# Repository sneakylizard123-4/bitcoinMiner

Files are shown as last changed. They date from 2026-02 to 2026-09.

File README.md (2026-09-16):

# BitcoinMiner

A single BM1370 board that mines bitcoin

## Custom Features
- BM1370 ASIC miner
- ESP32-S3-WROOM-1/1u-N16R8 MCU for wifi
- 9x WS2812B status LEDs
- Fan controller
- TPS546D24 20A core regulator
- USB-C + TC2030 Tag-Connect

## PCB Design

The board is a 4 layer 100x75mm PCB with a dedicated ground inner layer

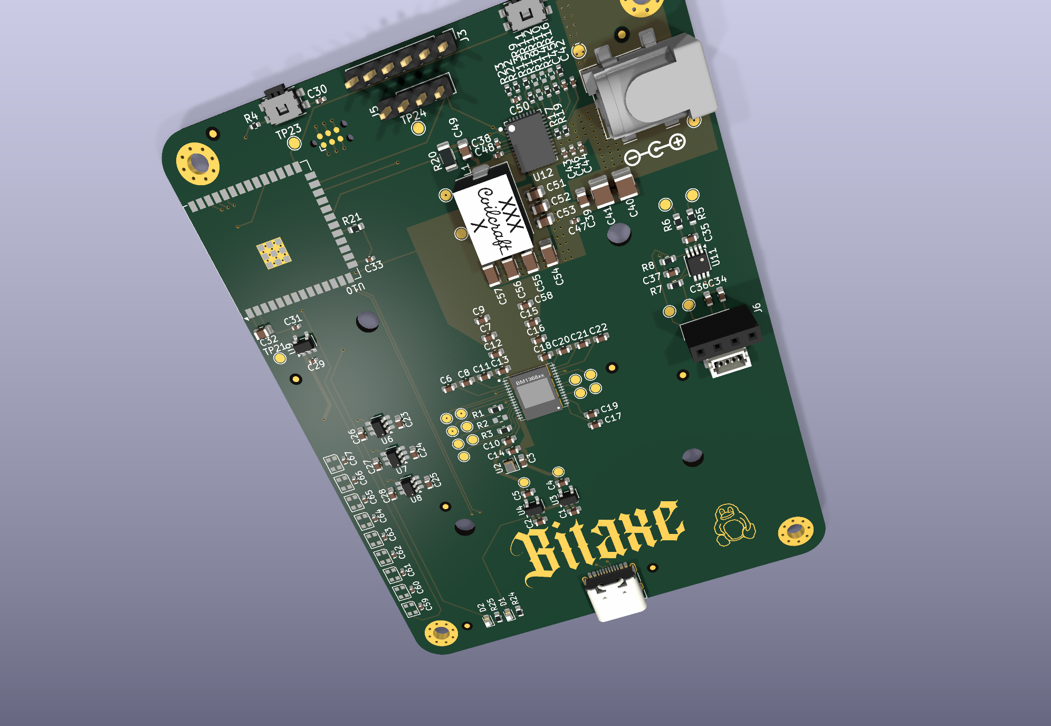
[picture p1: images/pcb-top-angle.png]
PCB 3D / layout image


It is built around the BM1370 ASIC.
it is based on the proven Bitaxe Gamma reference design, and a buck 20A 1.2V core rail.
The ESP32-S3 module provides WiFi/BLE control. It can be programmed through the native USB-C port or the Tag-Connect debug header
The fan controller communicates to the ESP32 via i2C

## Firmware

The firmware is the open-source
see [firmware/](firmware/). 
To enter program mode:
1. Hold BOOT (SW2)
2. Press RESET (SW1)
3. Release BOOT
4. Start flashing

```
pip install bitaxetool
bitaxetool --config firmware/configs/config-bitcoinMiner.csv --firmware firmware/esp-miner-merged.bin
```

## BOM (Bill of Materials)

| Ref | Value | LCSC # | MPN | Manufacturer | Footprint | Qty | Unit $ | Ext $ | Link |
|-----|---|---|-----|---|---|-----|---|---|---|
| C1,C2,C4-C22,C58 | 1uF 16V X7R | C59782 | CL10B105KO8NNNC | Samsung | 0603 | 22 | — | — | [LCSC](https://www.lcsc.com/product-detail/C59782.html) |
| C3,C23-C28,C36,C37 | 0.1uF 16V X7R | C66501 | CL10B104KO8NNNC | Samsung | 0603 | 9 | — | — | [LCSC](https://www.lcsc.com/product-detail/C66501.html) |
| C29,C30,C31,C38,C42,C44 | 1uF 16V X5R | C2177690 | EMK105BJ105MV | Taiyo Yuden | 0402 | 6 | — | — | [LCSC](https://www.lcsc.com/product-detail/C2177690.html) |
| C32,C39 | 10uF 16V X5R | C1713 | CL21A106KOQNNNE | Samsung | 0805 | 2 | — | — | [LCSC](https://www.lcsc.com/product-detail/C1713.html) |
| C33,C45,C48,C59-C67 | 0.1uF 16V X5R | C159816 | CL05A104KO5NNNC | Samsung | 0402 | 12 | — | — | [LCSC](https://www.lcsc.com/product-detail/C159816.html) |
| C34 | 47uF 6.3V X5R | C140782 | GRM188R60J476ME15D | muRata | 0603 | 1 | — | — | [LCSC](https://www.lcsc.com/product-detail/C140782.html) |
| C35 | 470pF 50V C0G | C36252 | 0603CG471J500NT | FH | 0603 | 1 | — | — | [LCSC](https://www.lcsc.com/product-detail/C36252.html) |
| C40,C41 | 47uF 16V X5R | C2932477 | CL32A476KOJNNNE | Samsung | 1210 | 2 | — | — | [LCSC](https://www.lcsc.com/product-detail/C2932477.html) |
| C43 | 4700pF 50V X7R | C599603 | C0402C472K5RAC7867 | KEMET | 0402 | 1 | — | — | [LCSC](https://www.lcsc.com/product-detail/C599603.html) |
| C46 | 2200pF 50V X7R | C106861 | CC0402KRX7R9BB222 | YAGEO | 0402 | 1 | — | — | [LCSC](https://www.lcsc.com/product-detail/C106861.html) |
| C47 | 4.7uF 6.3V X5R | C82453 | GRM155R60J475ME47D | muRata | 0402 | 1 | — | — | [LCSC](https://www.lcsc.com/product-detail/C82453.html) |
| C49 | 1000pF 50V NP0 | C152850 | 0805N102J500CT | Walsin | 0805 | 1 | — | — | [LCSC](https://www.lcsc.com/product-detail/C152850.html) |
| C50 | 100pF 50V C0G | C597014 | 04025A101JAT2A | AVX | 0402 | 1 | — | — | [LCSC](https://www.lcsc.com/product-detail/C597014.html) |
| C51,C52,C53 | 22uF 10V X5R | C441864 | GRM21BR61A226ME44L | muRata | 0805 | 3 | — | — | [LCSC](https://www.lcsc.com/product-detail/C441864.html) |
| C54-C57 | 100uF 6.3V X5R | C15008 | CL31A107MQHNNNE | Samsung | 1206 | 4 | — | — | [LCSC](https://www.lcsc.com/product-detail/C15008.html) |
| D1,D2 | Green LED 0603 | C12624 | KT-0603G | Hubei KENTO | 0603 | 2 | — | — | [LCSC](https://www.lcsc.com/product-detail/C12624.html) |
| D3-D11 | WS2812B-2020 | C965555 | WS2812B-2020 | Worldsemi | PLCC4 2020 | 9 | — | — | [LCSC](https://www.lcsc.com/product-detail/C965555.html) |
| J1 | DC Barrel Jack 2.0x5.5mm | C431534 | 694106106102 | Wuerth | Through Hole | 1 | — | — | [LCSC](https://www.lcsc.com/product-detail/C431534.html) |
| J4 | USB-C Receptacle 16P | C165948 | TYPE-C-31-M-12 | Korean Hroparts Elec | SMD | 1 | — | — | [LCSC](https://www.lcsc.com/product-detail/C165948.html) |
| J6 | Pin Socket 1x4 2.54mm | C2718488 | 2.54-1\*4P | BOOMELE | Through Hole | 1 | — | — | [LCSC](https://www.lcsc.com/product-detail/C2718488.html) |
| J7 | JST SH 4P 1mm | C160390 | BM04B-SRSS-TB(LF)(SN) | JST | SMD | 1 | — | — | [LCSC](https://www.lcsc.com/product-detail/C160390.html) |
| L1 | 300nH Shielded Inductor | — | SLC1175-271MEC | Coilcraft | SMD 11x17mm | 1 | — | — | — |
| R1,R3 | 1K 1% | C22548 | RC0603FR-071KL | YAGEO | 0603 | 2 | — | — | [LCSC](https://www.lcsc.com/product-detail/C22548.html) |
| R13 | 14.7k 1% | C4021671 | CRCW040214K7FKTD | Vishay | 0402 | 1 | — | — | [LCSC](https://www.lcsc.com/product-detail/C4021671.html) |
| R14 | 0 ohm | C881153 | CR0402J0R00Q10Z | Ever Ohms | 0402 | 1 | — | — | [LCSC](https://www.lcsc.com/product-detail/C881153.html) |
| R16 | 3.74k 1% | C2085340 | CRCW04023K74FKED | Vishay | 0402 | 1 | — | — | [LCSC](https://www.lcsc.com/product-detail/C2085340.html) |
| R17 | 11.8k 1% | C324858 | RC-02K1182FT | FH | 0402 | 1 | — | — | [LCSC](https://www.lcsc.com/product-detail/C324858.html) |
| R18 | 68.1k 1% | C844116 | CRCW040268K1FKED | Vishay | 0402 | 1 | — | — | [LCSC](https://www.lcsc.com/product-detail/C844116.html) |
| R19 | 10 1% | C138066 | RC0402FR-0710RL | YAGEO | 0402 | 1 | — | — | [LCSC](https://www.lcsc.com/product-detail/C138066.html) |
| R20 | 1 ohm 0.1% sense | C2912606 | HoAR1206-1/4W-1R-0.1% | Milliohm | 1206 | 1 | — | — | [LCSC](https://www.lcsc.com/product-detail/C2912606.html) |
| R8,R21,R24,R25 | 10k 1% | C98220 | RC0603FR-0710KL | YAGEO | 0603 | 4 | — | — | [LCSC](https://www.lcsc.com/product-detail/C98220.html) |
| R22,R23 | 49.9 1% | C482189 | CRCW040249R9FKED | Vishay | 0402 | 2 | — | — | [LCSC](https://www.lcsc.com/product-detail/C482189.html) |
| R4 | 10k 1% | C60490 | RC0402FR-0710KL | YAGEO | 0402 | 1 | — | — | [LCSC](https://www.lcsc.com/product-detail/C60490.html) |
| R5,R6 | 100 1% | C100700 | CR0603FA1000G | LIZ | 0603 | 2 | — | — | [LCSC](https://www.lcsc.com/product-detail/C100700.html) |
| R7 | 5.6K 1% | C844799 | CRCW06035K60FKEA | Vishay | 0603 | 1 | — | — | [LCSC](https://www.lcsc.com/product-detail/C844799.html) |
| R9 | 8.25k 1% | C185389 | RC0402FR-078K25L | YAGEO | 0402 | 1 | — | — | [LCSC](https://www.lcsc.com/product-detail/C185389.html) |
| SW1,SW2 | Tactile Switch EVQPU | — | EVQPUM02K | PANASONIC | SMD | 2 | — | — | — |
| U10 | ESP32-S3-WROOM-1N16R8 | C2913202 | ESP32-S3-WROOM-1-N16R8 | ESPRESSIF | SMD WROOM | 1 | — | — | [LCSC](https://www.lcsc.com/product-detail/C2913202.html) |
| U11 | EMC2101 | C626968 | EMC2101-R-ACZL-TR | Microchip | TSSOP-8 | 1 | — | — | [LCSC](https://www.lcsc.com/product-detail/C626968.html) |
| U12 | TPS546D24ARVFR | C507280 | TPS546D24ARVFR | TI | LQFN-40 | 1 | — | — | [LCSC](https://www.lcsc.com/product-detail/C507280.html) |
| U2 | 25MHz Crystal | C843258 | NX2016SA-25MHZ-STD-CZS-2 | NDK | 2016-4P | 1 | — | — | [LCSC](https://www.lcsc.com/product-detail/C843258.html) |
| U3 | TLV75712PDBV | C1509296 | TLV75712PDBVR | TI | SOT-23-5 | 1 | — | — | [LCSC](https://www.lcsc.com/product-detail/C1509296.html) |
| U4 | MCP1824T-0802E | C625460 | MCP1824T-0802E/OT | Microchip | SOT-23-5 | 1 | — | — | [LCSC](https://www.lcsc.com/product-detail/C625460.html) |
| U5 | BM1370 | — | BM1370 | Bitmain | LQFP | 1 | — | — | — |
| U6,U7,U8 | SN74LVC1T45DBV | C7843 | SN74LVC1T45DBVR | TI | SOT-23-6 | 3 | — | — | [LCSC](https://www.lcsc.com/product-detail/C7843.html) |
| U9 | TLV75733PDBV | C485517 | TLV75733PDBVR | TI | SOT-23-5 | 1 | — | — | [LCSC](https://www.lcsc.com/product-detail/C485517.html) |
| **Total** | — | — | — | — | — | **116** | — | — | — |

Full CSVs: [LCSC BOM](BOM.csv)
[KiCad generated BOM](kicad/production/bom.csv)
[Pick and place](kicad/production/positions.csv)

## Production

Using JLCPCB
4-Layer
- HASL Lead Free
- 1.6mm thick board

## Credits

- [Bitaxe Gamma](https://github.com/bitaxeorg/BitaxeGamma) - reference schematic and BM1370 support circuitry
- [ESP-Miner](https://github.com/bitaxeorg/ESP-Miner) - firmware this board's target is based on
- [Hack Club](https://hackclub.com/) - funding through Forge

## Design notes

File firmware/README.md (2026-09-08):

# bitcoinMiner Firmware

ESP32-S3 mining firmware for the bitcoinMiner board, based on the open-source
[bitaxe ESP-Miner](https://github.com/bitaxeorg/ESP-Miner) firmware (GPL-3.0,
ESP-IDF v6.0.x). The entire upstream tree is vendored under `firmware/` with a
custom **BitcoinMiner** board target added, so the board tunnels a single
BitMiner BM1370 ASIC at ~525 MHz / 1.15 V core like a Bitaxe Gamma.

## Board target

Added to the upstream ESP-Miner:

| File | Change |
|---|---|
| `main/device_pins.h` / `main/device_pins.c` | `BITCOINMINER_I2C_PINS` (SDA=48, SCL=47) |
| `main/device_config.h` | `BITCOINMINER` family + `board_version = "bitcoinMiner"` config |
| `configs/config-bitcoinMiner.csv` | NVS config flashed with `bitaxetool` |

Board version string: **`bitcoinMiner`**

### How the board is selected

`device_config_init()` (in `device_config.c`) looks up `boardversion` from NVS
against `default_configs[]`. The `bitcoinMiner` entry selects:

- Family `BitcoinMiner`: 1x BM1370, default 525 MHz, 1150 mV, 128 cores, 4 hash domains
- `BITCOINMINER_PINS`: I2C SDA=GPIO48, SCL=GPIO47 (EMC2101 at 0x4C, TPS546D24 at 0x24 on PMBus)
- `EMC2101` fan/temp controller enabled (ideality 0x24, beta 0x00)
- `TPS546` PMBus core regulator enabled (VOUT 1.2 V core rail)
- No BAP, no display (`.bap = NULL, .i80 = NULL`)
- `asic_enable = false`, `plug_sense = false` (core power is always on via TPS546; barrel jack has no sense pin)

## ESP32 pin map

| Signal | ESP32-S3 GPIO | Notes |
|---|---|---|
| ASIC serial TX (→U7→BM1370 CI) | GPIO17 | UART1, hardcoded in `components/asic/serial.c` |
| ASIC serial RX (←U8←BM1370 RO) | GPIO18 | UART1 |
| ASIC reset (→U6→BM1370 NRSTI) | GPIO1 | `CONFIG_GPIO_ASIC_RESET`, default already 1 |
| I2C SDA (EMC2101, TPS546D24) | GPIO48 | `BITCOINMINER_I2C_PINS` |
| I2C SCL | GPIO47 | |
| WS2812B LED chain (D3–D11) | GPIO38 | Not driven by ESP-Miner (no RGB LED support); reserved |
| Boot button (SW2) | GPIO0 | default boot button |
| USB D− / D+ | GPIO19 / GPIO20 | USB-C flashing |
| UART0 console (J2 TC2030) | GPIO43 (RX) / GPIO44 (TX) | debug |
| Board LED D2 | GPIO21 | not used by firmware |
| TPS546 Power Good (PGD) | GPIO11 | not used by firmware |
| TPS546 SMB_ALERT | GPIO13 | not used by firmware |

GPIO2 is tied to the 1.2 V ASIC core rail on the PCB — do not configure it as an output.

## Build

Requires ESP-IDF v6.0.x for ESP32-S3 and Node.js ≥ 22 (the AxeOS web UI is
compiled into the binary). See upstream `AGENTS.md` / `readme.md` for the exact
SDK and the official devcontainer if you don't want to install the toolchain.

```
cd firmware
git clone ... # upstream expects the libsecp256k1 component vendored here already
. $HOME/esp/v6.0.2/esp-idf/export.sh
idf.py set-target esp32s3
idf.py build
./merge_bin.sh ./esp-miner-merged.bin
```

## Flash

Install [bitaxetool](https://pypi.org/project/bitaxetool/):

```
pip install bitaxetool
bitaxetool --config ./configs/config-bitcoinMiner.csv --firmware ./esp-miner-merged.bin
```

Or flash over USB-C (J4) / TC2030 (J2):

1. Hold **SW1** (boot) and press **SW2** (reset) to enter download mode.
2. `esptool.py --chip esp32s3 --port /dev/ttyACM0 write_flash 0x0 esp-miner-merged.bin`
3. Press **SW2** (reset) to boot, then configure WiFi/pool from the AxeOS UI
   (captive portal AP `bitcoinminer`).

## What's not wired up

- **WS2812B status LEDs (GPIO38)**: upstream ESP-Miner has no RGB/LED-strip
  support, so the LED chain stays dark. Wiring it to the firmware would need a
  new feature (e.g. led_strip + status colors) that doesn't exist upstream.
- **Board LED D2 (GPIO21)** and TPS546 PGD/SMB_ALERT (GPIO11/13) are reserved
  but unused by the firmware.

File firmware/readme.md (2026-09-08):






Repobeats analytics image

# ESP-Miner
esp-miner is open source ESP32 firmware for the [Bitaxe](https://github.com/bitaxeorg/bitaxe)

## Community
The ESP-Miner firmware is maintained by OSMU which hosts it's own discussion forum at [Forum](https://osmu.xyz).

If you are looking for premade images to load on your Bitaxe, check out the [latest release](https://github.com/bitaxeorg/ESP-Miner/releases/latest) page. Maybe you want [instructions](https://github.com/bitaxeorg/ESP-Miner/blob/master/flashing.md) for loading factory images.

# Bitaxetool
We also have a command line python tool for flashing Bitaxe and updating the config called Bitaxetool 

**Bitaxetool Requires Python3.4 or later and pip**

Install bitaxetool from pip. pip is included with Python 3.4 but if you need to install it check <https://pip.pypa.io/en/stable/installation/>

```
pip install --upgrade bitaxetool
```
The bitaxetool includes all necessary library for flashing the binaries to the Bitaxe Hardware.

**Notes**
 - The bitaxetool does not work properly with esptool v5.x.x, esptool v4.9.0 or earlier is required.
 - Bitaxetool v0.6.1 - locked to using esptool v4.9.0

```
pip install bitaxetool==0.6.1
```

- Flash a "factory" image to a Bitaxe to reset to factory settings. Make sure to choose an image built for your hardware version (401) in this case:

```
bitaxetool --firmware ./esp-miner-factory-401-v2.4.2.bin
```
- Flash just the NVS config to a bitaxe:

```
bitaxetool --config ./configs/config-401.csv
```
- Flash both a factory image _and_ a config to your Bitaxe: note the settings in the config file will overwrite the config already baked into the factory image:

```
bitaxetool --config ./configs/config-401.csv --firmware ./esp-miner-factory-401-v2.4.2.bin
```

## AxeOS API
The esp-miner UI is called AxeOS and provides an API to expose actions and information.

For more details take a look at [`main/http_server/openapi.yaml`](./main/http_server/openapi.yaml).

Available API endpoints:
  
**GET**

* `/api/system/info` Get system information
* `/api/system/asic` Get ASIC settings information
* `/api/system/statistics` Get system statistics (data logging should be activated)
* `/api/system/statistics/dashboard` Get system statistics for dashboard
* `/api/system/scoreboard` Get top 20 highest difficulty shares
* `/api/system/wifi/scan` Scan for available Wi-Fi networks
* `/api/system/logs` Download system logs

**POST**

* `/api/system/restart` Restart the system
* `/api/system/identify` Identify the device
* `/api/system/OTA` Update system firmware
* `/api/system/OTAWWW` Update AxeOS

**PATCH**

* `/api/system` Update system settings

**WEBSOCKETS**

* `/api/ws` Text stream log
* `/api/ws/live` JSONp stream of partial system info updates

### API examples in `curl` (works with IP addresses or .local hostnames):

```bash
# Get system information
curl http://YOUR-BITAXE-IP/api/system/info

# Get ASIC settings information
curl http://YOUR-BITAXE-IP/api/system/asic

# Get system statistics
curl http://YOUR-BITAXE-IP/api/system/statistics

# Get dashboard statistics
curl http://YOUR-BITAXE-IP/api/system/statistics/dashboard

# Get available Wi-Fi networks
curl http://YOUR-BITAXE-IP/api/system/wifi/scan

# Download system logs
curl http://YOUR-BITAXE-IP/api/system/logs

# Restart the system
curl -X POST http://YOUR-BITAXE-IP/api/system/restart

# Pause mining
curl -X POST http://YOUR-BITAXE-IP/api/system/pause

# Resume mining
curl -X POST http://YOUR-BITAXE-IP/api/system/resume

# Let the device say Hi!
curl -X POST http://YOUR-BITAXE-IP/api/system/identify

# Update system firmware
curl -X POST \
     -H "Content-Type: application/octet-stream" \
     --data-binary "@esp-miner.bin" \
     http://YOUR-BITAXE-IP/api/system/OTA

# Update with a custom AxeOS Web UI partition (www.bin)
curl -X POST \
     -H "Content-Type: application/octet-stream" \
     --data-binary "@www.bin" \
     http://YOUR-BITAXE-IP/api/system/OTAWWW

# Update system settings
curl -X PATCH http://YOUR-BITAXE-IP/api/system \
     -H "Content-Type: application/json" \
     -d '{"fanspeed": "desired_speed_value"}'

# Configure a Stratum V1 Pool (Slot Index 0)
curl -X PUT http://YOUR-BITAXE-IP/api/system/pools/0 \
     -H "Content-Type: application/json" \
     -d '{
       "stratumProtocol": "SV1",
       "stratumURL": "solo.ckpool.org",
       "stratumPort": 3333,
       "stratumUser": "1A1zP1eP5QGefi2DMPTfTL5SLmv7DivfNa.worker1",
       "stratumPassword": "x",
       "stratumSuggestedDifficulty": 0,
       "stratumExtranonceSubscribe": true,
       "stratumTLS": 0,
       "stratumDecodeCoinbase": true
     }'

# Configure a Stratum V2 Pool (Slot Index 1)
curl -X PUT http://YOUR-BITAXE-IP/api/system/pools/1 \
     -H "Content-Type: application/json" \
     -d '{
       "stratumProtocol": "SV2",
       "stratumURL": "v2.srtm.ocean.xyz",
       "stratumPort": 3334,
       "stratumUser": "1A1zP1eP5QGefi2DMPTfTL5SLmv7DivfNa.worker1",
       "stratumPassword": "x",
       "stratumSuggestedDifficulty": 0,
       "stratumExtranonceSubscribe": true,
       "stratumTLS": 0,
       "stratumDecodeCoinbase": true,
       "stratumV2ChannelType": "extended",
       "stratumV2AuthorityPubkey": "your_base58_sv2_authority_public_key"
     }'

# Stream logs
websocat ws://YOUR-BITAXE-IP/api/ws

# Stream Info API
websocat ws://YOUR-BITAXE-IP/api/ws/live
```

## mDNS Support

ESP-Miner now includes comprehensive mDNS (multicast DNS) support for seamless network discovery and device accessibility. This feature enables automatic device discovery on local networks without requiring manual IP address configuration.

### Features

- **Automatic mDNS Initialization**: Device automatically registers with mDNS/Bonjour/Avahi services on network connection
- **Dynamic Hostname Registration**: Device hostname is registered as `<hostname>.local` (e.g., `bitaxe.local`)
- **Service Advertisement**: HTTP service is advertised as `_http._tcp` on port 80
- **AxeOS Subtype**: Advertises `_axeos._sub._http._tcp` for targeted DNS-SD discovery of AxeOS devices
- **Device TXT Records**: Includes board version, family, ASIC model, ASIC count, and firmware version as DNS-SD TXT records
- **Dynamic Hostname Updates**: mDNS hostname updates automatically when device hostname is changed via web interface
- **Hostname Normalization**: Automatically strips `.local` suffix when setting hostnames to prevent duplicate registrations
- **CORS Support**: Enhanced CORS handling to allow requests from mDNS hostnames
- **Hostname Conflict Resolution**: Automatically detects and resolves hostname conflicts by appending MAC address suffix when needed
- **Enhanced Swarm Discovery**: Swarm mode supports both IP addresses and .local hostnames for seamless network management

### Network Discovery

Once connected to your local network, the device becomes discoverable through:

```bash
# Using avahi-browse (Linux)
avahi-browse _http._tcp

# Discover AxeOS devices specifically
avahi-browse _axeos._sub._http._tcp

# Using dns-sd (macOS)
dns-sd -B _http._tcp

# Discover AxeOS devices with TXT records
dns-sd -B _axeos._sub._http._tcp

# Direct access
http://<hostname>.local
```

### Configuration

- **Default Hostname**: `bitaxe` (configurable via web interface)
- **Service Type**: `_http._tcp`
- **Subtype**: `_axeos._sub._http._tcp`
- **Port**: `80`
- **Instance Name**: `Bitaxe <family> <board> (<mac_suffix>)` (e.g., `Bitaxe Gamma 601 (A1B2)`)
- **TXT Records**: `board`, `family`, `asic`, `asic_count`, `fw_version`

### Hostname Conflict Resolution

If multiple devices attempt to use the same hostname, ESP-Miner automatically resolves conflicts by appending a MAC address-derived suffix (e.g., `bitaxe-12ab` if `bitaxe` is taken). This ensures unique network identification without manual intervention.

### Benefits

- **Zero-Configuration Discovery**: Devices automatically appear in network browsers
- **Cross-Platform Compatibility**: Works with Windows, macOS, Linux, and mobile devices
- **No IP Address Required**: Access devices using human-readable names
- **Automatic Resolution**: DNS resolution happens transparently in the background
- **Zero-Configuration Swarm Management**: Automatic device discovery and management without IP configuration
- **Enhanced Cross-Platform Compatibility**: Improved support across different network environments and discovery protocols

## Administration

The firmware hosts a small web server on port 80 for administrative purposes. Once the Bitaxe device is connected to the local network, the admin web front end may be accessed via a web browser connected to the same network at `http://<IP>`, replacing `IP` with the LAN IP address of the Bitaxe device, or `http://bitaxe`, provided your network supports mDNS configuration.

### Recovery

In the event that the admin web front end is inaccessible, for example because of an unsuccessful custom Web UI update, a recovery page can be accessed at `http://<IP>/recovery`.

### Unlock Settings

In order to unlock the Input fields for ASIC Frequency and ASIC Core Voltage you need to append `?oc` to the end of the settings tab URL in your browser. Be aware that without additional cooling overclocking can overheat and/or damage your Bitaxe.

## Unified Firmware & Rollbacks

Starting with the unified firmware releases, ESP-Miner uses a unified architecture where the AxeOS frontend is compiled, gzipped, and embedded directly into the firmware application binary (`esp-miner.bin`). 

A separate Web UI image (`www.bin`) is no longer required for standard usage since the web interface is served directly from the firmware. If you want to use a custom or modified AxeOS frontend, you can still enable the **custom web UI** option in the settings. This allows you to upload and serve a separate `www.bin` from the SPIFFS partition, which takes priority over the built-in assets.

### Disabling Custom Web UI via Recovery Page or API

If a device is stuck serving an older custom `www.bin` partition and the Web UI settings option is not accessible, you can disable custom WWW and revert to the embedded AxeOS interface by visiting the recovery page in your browser:

```
http://<IP>/recovery
```

Alternatively, you can disable `useCustomWWW` directly via the REST API:

```bash
# Disable custom Web UI (revert to embedded AxeOS)
curl -X PATCH http://YOUR-BITAXE-IP/api/system \
     -H "Content-Type: application/json" \
     -d '{"useCustomWWW": 0}'

# Restart the device to apply changes
curl -X POST http://YOUR-BITAXE-IP/api/system/restart
```

### Rollback to Pre-Unified Firmware

If you roll back the firmware from a unified version to an older, pre-unified version (which expects a separate web partition):

- **www partition persistence**: The `www` (SPIFFS) partition on the flash chip will remain untouched during the rollback, keeping whatever latest non-unified Web UI version was last active on the device.
- **Potential UI Version Mismatch**: Since older firmware relies entirely on the separate `www` partition to serve the web interface, the device will load whatever files exist in that partition. If you experience layout errors or missing features after rolling back, you will need to manually flash or upload a compatible `www.bin` version that matches the older firmware version.

## Development using esp-miner/devcontainer

This configuration allows you to edit locally and compile the source code using a docker container so you don't have to install the ESP-IDF toolchain and other supporting software on your computer to compile the firmware.

### Prerequisites

- Docker server

### Local PC Setup

These instructions will assume an installation to your home directory.
```
cd ~
git clone --recursive https://github.com/bitaxeorg/ESP-MINER.git
cd ESP-MINER
git checkout <the branch you want>
git submodule update --init --recursive
# The next step builds the docker container that will compile the source code
# This will take several minutes to finish
docker build -t espminer-build .devcontainer
```
### Building

```
cd ~/ESP-MINER
docker run --rm -it -v $PWD:/workspace espminer-build /bin/bash
git config --global --add safe.directory /workspace    # set git permissions or build will fail; only done once
cd /workspace
idf.py build
```	
Once the build is done exit out of the docker session and flash the new firmware.

## Development

### Prerequisites

- Install the ESP-IDF toolchain from https://docs.espressif.com/projects/esp-idf/en/stable/esp32/get-started/
- Install nodejs/npm from https://nodejs.org/en/download
- (Optional) Install the ESP-IDF extension for VSCode from https://marketplace.visualstudio.com/items?itemName=espressif.esp-idf-extension

### Cloning

This project uses git submodules (e.g. libsecp256k1). Clone with `--recursive`:
```
git clone --recursive https://github.com/bitaxeorg/ESP-Miner.git
```

If you already have a checkout, initialize the submodules with:
```
git submodule update --init --recursive
```

### Building

At the root of the repository, run:
```
idf.py build && ./merge_bin.sh ./esp-miner-merged.bin
```

Note: the merge_bin.sh script is a custom script that merges the bootloader, partition table, and the application binary into a single file.

Note: if using VSCode, you may have to configure the settings.json file to match your esp hardware version. For example, if your bitaxe has something other than an esp32-s3, you will need to change the version in the `.vscode/settings.json` file.

### Flashing

With the bitaxe connected to your computer via USB, run:

```
bitaxetool --config ./configs/config-xxx.csv --firmware ./esp-miner-merged.bin
```

where xxx is the config file for your hardware version. You can see the list of available config files in the `configs` directory.

A custom board version is also possible with `configs/config-custom.csv`. A custom board needs to be based on an existing `devicemodel` and `asicmodel`.

**Notes:** 
  - If you are developing within a dev container, you will need to run the bitaxetool command from outside the container. Otherwise, you will get an error about the device not being found.
  - Some Bitaxe versions can't directly connect to a USB-C port. If yours is affected use a USB-A adapter as a workaround. More about it [here](https://github.com/bitaxeorg/bitaxeGamma/issues/37).
  - Only ESP32-S3-WROOM-1 module type N16R8 (16MB Flash, 8MB Octal SPI PSRAM) is supported. This model number should be visible on the ESP32 module. Other module types without PSRAM or with Quad SPI PSRAM will not work with the normal firmware. More about it [here](https://github.com/bitaxeorg/ESP-Miner/issues/826).

### Wi-Fi routers

There are some Wi-Fi routers that will block mining, ASUS Wi-Fi routers & some TP-Link Wi-Fi routers for example.
If you find that your not able to mine / have no hash rate you will need to check the Wi-Fi routers settings and disable the following;

1/ AiProtection

2/ IoT 

If your Wi-Fi router has both of these options you might have to disable them both.

If your still having problems here, check other settings within the Wi-Fi router and the bitaxe device, this includes the URL for
the Stratum Host and Stratum Port.

## Attributions

The display font is Portfolio 6x8 from https://int10h.org/oldschool-pc-fonts/ by VileR.

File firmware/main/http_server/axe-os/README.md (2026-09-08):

# AxeOS

The Angular frontend for the Bitaxe open-source Bitcoin miner. All commands can be run either from this directory or from the **repository root** (commands are forwarded via the root `package.json`).

## Development server

### Mock data (no device required)

```bash
npm run start
```

Navigate to `http://localhost:4200/`. The app will use built-in mock data so you can develop the UI without a real device. HMR is enabled — style changes apply instantly, template/TypeScript changes trigger a full page reload.

### Live device (proxy to real hardware)

To connect the dev server to an actual Bitaxe on your local network:

```bash
BITAXE_IP=192.168.1.152 npm run start:proxy
```

- Replace `192.168.1.152` with your device's IP address.
- If `BITAXE_IP` is omitted, the proxy falls back to `http://192.168.1.100`.
- All `/api` HTTP and WebSocket traffic is forwarded to the device via `proxy.conf.js`.
- The `Origin` header is automatically rewritten to pass the device's private-network CORS check.

The `mock` flag in `src/environments/environment.ts` is `false` by default, so the real device API is used when running with the proxy. If you switch back to `npm run start` (no proxy), set `mock: true` in that file to re-enable mock data.

## Build

```bash
npm run build
```

Generates the production bundle, gzip-compresses assets, and writes a `version.txt`. Build artifacts are stored in `dist/axe-os/`.

## Running unit tests

```bash
npm run test:ci
```

Runs all Karma/Jasmine unit tests in a headless Chrome environment. Also accepts the plain `npm run test` variant for interactive (watch) mode.

```bash
export CHROME_BIN=/snap/bin/chromium   # adjust path for your system
npm run test
```

## Code generation

After modifying `../openapi.yaml`, regenerate the TypeScript API client:

```bash
npm run generate:api
```

This is also run automatically as part of `npm run build` and `npm run test:ci`.

## Further help

To get more help on the Angular CLI use `ng help` or check out the [Angular CLI Overview and Command Reference](https://angular.io/cli).

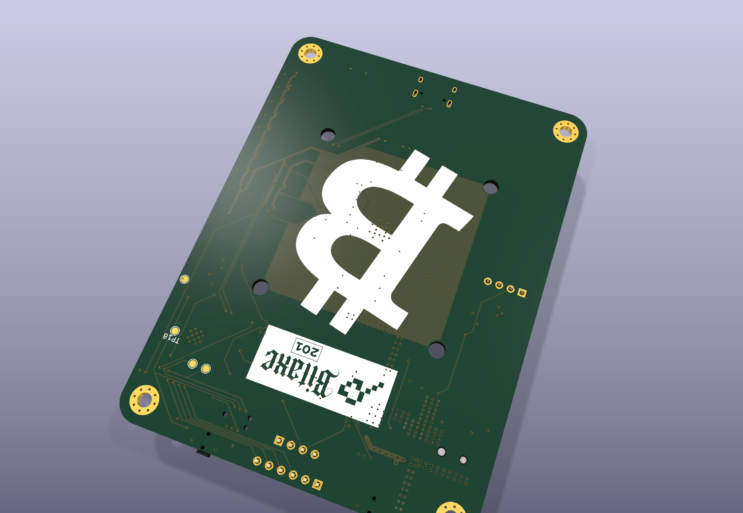
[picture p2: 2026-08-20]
images/pcb-back-angle.png

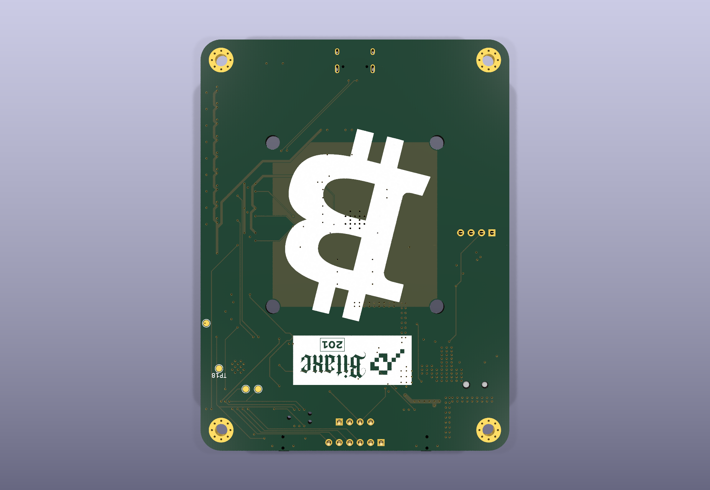
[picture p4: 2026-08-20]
images/pcb-bottom.png

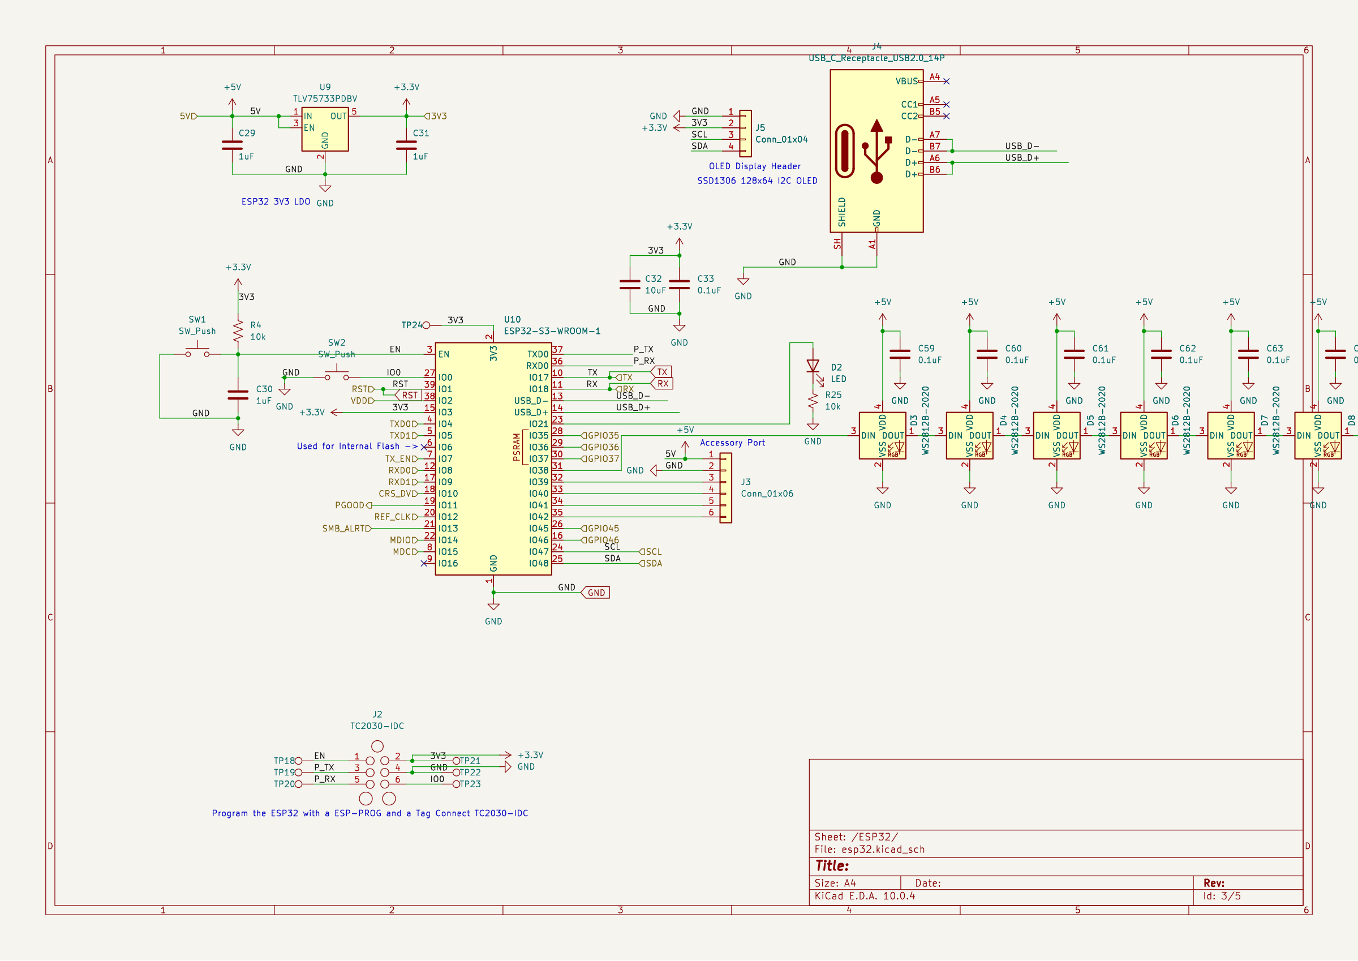
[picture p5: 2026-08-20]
images/bitcoinMiner-ESP32.png

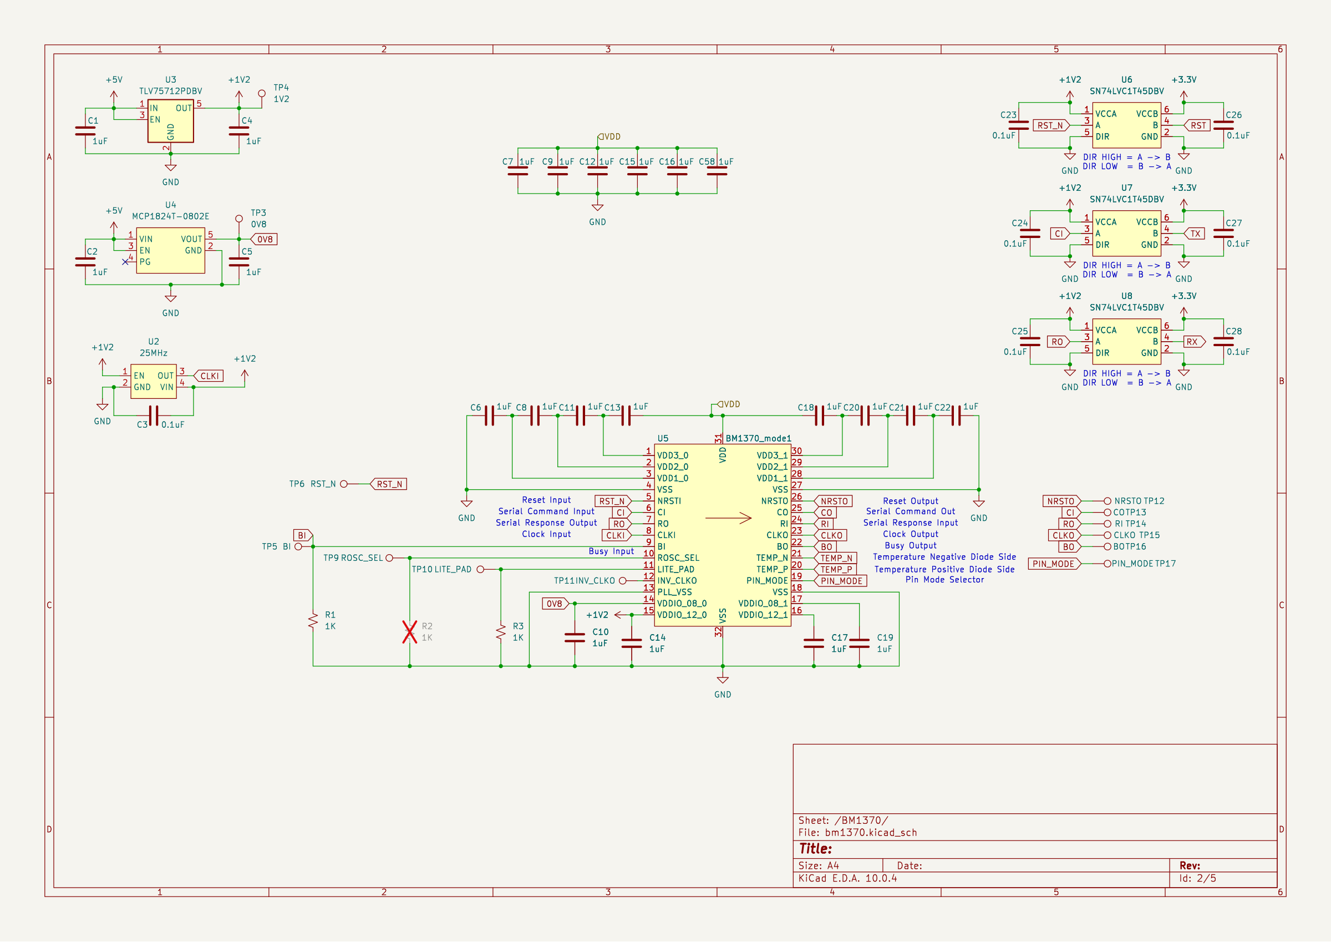
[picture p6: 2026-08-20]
images/bitcoinMiner-BM1370.png

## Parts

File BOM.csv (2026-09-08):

Designator | Footprint | Quantity | Value | LCSC Part # | LCSC Link
C1, C10, C11, C12, C13, C14, C15, C16, C17, C18, C19, C2, C20, C21, C22, C4, C5, C58, C6, C7, C8, C9 | 0603 | 22 | 1uF | C59782 | https://www.lcsc.com/search?q=C59782
C23, C24, C25, C26, C27, C28, C3, C36, C37 | 0603 | 9 | 0.1uF | C66501 | https://www.lcsc.com/search?q=C66501
C29, C30, C31, C38, C42, C44 | 0402 | 6 | 1uF | C2177690 | https://www.lcsc.com/search?q=C2177690
C32, C39 | 0805 | 2 | 10uF | C1713 | https://www.lcsc.com/search?q=C1713
C33, C45, C48, C59, C60, C61, C62, C63, C64, C65, C66, C67 | 0402 | 12 | 0.1uF | C159816 | https://www.lcsc.com/search?q=C159816
C34 | 0603 | 1 | 47uF | C140782 | https://www.lcsc.com/search?q=C140782
C35 | 0603 | 1 | 470pF | C36252 | https://www.lcsc.com/search?q=C36252
C40, C41 | 1210 | 2 | 47uF | C2932477 | https://www.lcsc.com/search?q=C2932477
C43 | 0402 | 1 | 4700pF | C599603 | https://www.lcsc.com/search?q=C599603
C46 | 0402 | 1 | 2200pF | C106861 | https://www.lcsc.com/search?q=C106861
C47 | 0402 | 1 | 4.7uF | C82453 | https://www.lcsc.com/search?q=C82453
C49 | 0805 | 1 | 1000pF | C152850 | https://www.lcsc.com/search?q=C152850
C50 | 0402 | 1 | 100pF | C597014 | https://www.lcsc.com/search?q=C597014
C51, C52, C53 | 0805 | 3 | 22uF | C441864 | https://www.lcsc.com/search?q=C441864
C54, C55, C56, C57 | 1206 | 4 | 100uF | C15008 | https://www.lcsc.com/search?q=C15008
D1, D2 | 0603 | 2 | LED | C12624 | https://www.lcsc.com/search?q=C12624
D10, D11, D3, D4, D5, D6, D7, D8, D9 | LED_WS2812B-2020_PLCC4_2.0x2.0mm | 9 | WS2812B-2020 | C965555 | https://www.lcsc.com/search?q=C965555
J1 | BarrelJack_Wuerth_694106106102_2.0x5.5mm | 1 | 54-00164 | C431534 | https://www.lcsc.com/search?q=C431534
J4 | USB_C_Receptacle_HRO_TYPE-C-31-M-12 | 1 | USB_C_Receptacle_USB2.0_14P | C165948 | https://www.lcsc.com/search?q=C165948
J6 | PinSocket_1x04_P2.54mm_Vertical | 1 | Conn_01x04 | C2718488 | https://www.lcsc.com/search?q=C2718488
J7 | JST_SH_BM04B-SRSS-TB_1x04-1MP_P1.00mm_Vertical | 1 | Conn_01x04_MountingPin | C160390 | https://www.lcsc.com/search?q=C160390
L1 | L_Coilcraft_SLC1175 | 1 | 300nH SLC1175-271MEC_COC |  | Not on LCSC (Coilcraft) - order SLC1175-271MEC from Coilcraft/Mouser/DigiKey
R1, R3 | 0603 | 2 | 1K | C22548 | https://www.lcsc.com/search?q=C22548
R13 | 0402 | 1 | 14.7k | C4021671 | https://www.lcsc.com/search?q=C4021671
R14 | 0402 | 1 | 0 | C881153 | https://www.lcsc.com/search?q=C881153
R16 | 0402 | 1 | 3.74k | C2085340 | https://www.lcsc.com/search?q=C2085340
R17 | 0402 | 1 | 11.8k | C324858 | https://www.lcsc.com/search?q=C324858
R18 | 0402 | 1 | 68.1k | C844116 | https://www.lcsc.com/search?q=C844116
R19 | 0402 | 1 | 10 | C138066 | https://www.lcsc.com/search?q=C138066
R20 | 1206 | 1 | 1 | C2912606 | https://www.lcsc.com/search?q=C2912606
R21, R24, R25, R8 | 0603 | 4 | 10k | C98220 | https://www.lcsc.com/search?q=C98220
R22, R23 | 0402 | 2 | 49.9 | C482189 | https://www.lcsc.com/search?q=C482189
R4 | 0402 | 1 | 10k | C60490 | https://www.lcsc.com/search?q=C60490
R5, R6 | 0603 | 2 | 100 | C100700 | https://www.lcsc.com/search?q=C100700
R7 | 0603 | 1 | 5.6K | C844799 | https://www.lcsc.com/search?q=C844799
R9 | 0402 | 1 | 8.25k | C185389 | https://www.lcsc.com/search?q=C185389
SW1, SW2 | Panasonic_EVQPUM_EVQPUD | 2 | SW_Push |  | Not on LCSC (Panasonic EVQPU series) - order from Mouser/DigiKey
TP10 | TestPoint_Pad_D1.5mm | 1 | LITE_PAD |  | Bare test pad - no part
TP11 | TestPoint_Pad_D1.5mm | 1 | INV_CLKO |  | Bare test pad - no part
TP12 | TestPoint_Pad_D1.5mm | 1 | NRSTO |  | Bare test pad - no part
TP13 | TestPoint_Pad_D1.5mm | 1 | CO |  | Bare test pad - no part
TP14 | TestPoint_Pad_D1.5mm | 1 | RI |  | Bare test pad - no part
TP15 | TestPoint_Pad_D1.5mm | 1 | CLKO |  | Bare test pad - no part
TP16 | TestPoint_Pad_D1.5mm | 1 | BO |  | Bare test pad - no part
TP17 | TestPoint_Pad_D1.5mm | 1 | PIN_MODE |  | Bare test pad - no part
TP25 | TestPoint_Pad_D1.5mm | 1 | TEMP_P |  | Bare test pad - no part
TP26 | TestPoint_Pad_D1.5mm | 1 | TEMP_N |  | Bare test pad - no part
TP27 | TestPoint_Pad_D1.5mm | 1 | FAN_TACH |  | Bare test pad - no part
TP28 | TestPoint_Pad_D1.5mm | 1 | FAN_PWM |  | Bare test pad - no part
TP3 | TestPoint_Pad_D1.5mm | 1 | 0V8 |  | Bare test pad - no part
TP4 | TestPoint_Pad_D1.5mm | 1 | 1V2 |  | Bare test pad - no part
TP5 | TestPoint_Pad_D1.5mm | 1 | BI |  | Bare test pad - no part
TP6 | TestPoint_Pad_D1.5mm | 1 | RST_N |  | Bare test pad - no part
TP9 | TestPoint_Pad_D1.5mm | 1 | ROSC_SEL |  | Bare test pad - no part
U10 | ESP32-S3-WROOM-1U | 1 | ESP32-S3-WROOM-1 | C2913202 | https://www.lcsc.com/search?q=C2913202
U11 | TSSOP-8_3x3mm_P0.65mm | 1 | EMC2101 | C626968 | https://www.lcsc.com/search?q=C626968
U12 | LQFN40-CLIP | 1 | TPS546D24ARVFR | C507280 | https://www.lcsc.com/search?q=C507280
U2 | Crystal_SMD_2016-4Pin_2.0x1.6mm | 1 | 25MHz | C843258 | https://www.lcsc.com/search?q=C843258
U3 | SOT-23-5 | 1 | TLV75712PDBV | C1509296 | https://www.lcsc.com/search?q=C1509296
U4 | SOT-23-5 | 1 | MCP1824T-0802E | C625460 | https://www.lcsc.com/search?q=C625460
U5 | BM1370 | 1 | BM1370_mode1 |  | Not on LCSC (Bitmain ASIC) - source from Bitmain/secondary market
U6, U7, U8 | SOT-23-6_Handsoldering | 3 | SN74LVC1T45DBV | C7843 | https://www.lcsc.com/search?q=C7843
U9 | SOT-23-5 | 1 | TLV75733PDBV | C485517 | https://www.lcsc.com/search?q=C485517

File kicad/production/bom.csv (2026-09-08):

Designator | Footprint | Quantity | Value | LCSC Part #
C1, C10, C11, C12, C13, C14, C15, C16, C17, C18, C19, C2, C20, C21, C22, C4, C5, C58, C6, C7, C8, C9 | 0603 | 22 | 1uF
C23, C24, C25, C26, C27, C28, C3, C36, C37 | 0603 | 9 | 0.1uF
C29, C30, C31, C38, C42, C44 | 0402 | 6 | 1uF
C32, C39 | 0805 | 2 | 10uF
C33, C45, C48, C59, C60, C61, C62, C63, C64, C65, C66, C67 | 0402 | 12 | 0.1uF
C34 | 0603 | 1 | 47uF
C35 | 0603 | 1 | 470pF
C40, C41 | 1210 | 2 | 47uF
C43 | 0402 | 1 | 4700pF
C46 | 0402 | 1 | 2200pF
C47 | 0402 | 1 | 4.7uF
C49 | 0805 | 1 | 1000pF
C50 | 0402 | 1 | 100pF
C51, C52, C53 | 0805 | 3 | 22uF
C54, C55, C56, C57 | 1206 | 4 | 100uF
D1, D2 | 0603 | 2 | LED
D10, D11, D3, D4, D5, D6, D7, D8, D9 | LED_WS2812B-2020_PLCC4_2.0x2.0mm | 9 | WS2812B-2020
J1 | BarrelJack_Wuerth_694106106102_2.0x5.5mm | 1 | 54-00164 | C431534
J4 | USB_C_Receptacle_HRO_TYPE-C-31-M-12 | 1 | USB_C_Receptacle_USB2.0_14P
J6 | PinSocket_1x04_P2.54mm_Vertical | 1 | Conn_01x04
J7 | JST_SH_BM04B-SRSS-TB_1x04-1MP_P1.00mm_Vertical | 1 | Conn_01x04_MountingPin
L1 | L_Coilcraft_SLC1175 | 1 | 300nH SLC1175-271MEC_COC
R1, R3 | 0603 | 2 | 1K
R13 | 0402 | 1 | 14.7k
R14 | 0402 | 1 | 0
R16 | 0402 | 1 | 3.74k
R17 | 0402 | 1 | 11.8k
R18 | 0402 | 1 | 68.1k
R19 | 0402 | 1 | 10
R20 | 1206 | 1 | 1
R21, R24, R25, R8 | 0603 | 4 | 10k
R22, R23 | 0402 | 2 | 49.9
R4 | 0402 | 1 | 10k
R5, R6 | 0603 | 2 | 100
R7 | 0603 | 1 | 5.6K
R9 | 0402 | 1 | 8.25k
SW1, SW2 | Panasonic_EVQPUM_EVQPUD | 2 | SW_Push
TP10 | TestPoint_Pad_D1.5mm | 1 | LITE_PAD
TP11 | TestPoint_Pad_D1.5mm | 1 | INV_CLKO
TP12 | TestPoint_Pad_D1.5mm | 1 | NRSTO
TP13 | TestPoint_Pad_D1.5mm | 1 | CO
TP14 | TestPoint_Pad_D1.5mm | 1 | RI
TP15 | TestPoint_Pad_D1.5mm | 1 | CLKO
TP16 | TestPoint_Pad_D1.5mm | 1 | BO
TP17 | TestPoint_Pad_D1.5mm | 1 | PIN_MODE
TP25 | TestPoint_Pad_D1.5mm | 1 | TEMP_P
TP26 | TestPoint_Pad_D1.5mm | 1 | TEMP_N
TP27 | TestPoint_Pad_D1.5mm | 1 | FAN_TACH
TP28 | TestPoint_Pad_D1.5mm | 1 | FAN_PWM
TP3 | TestPoint_Pad_D1.5mm | 1 | 0V8
TP4 | TestPoint_Pad_D1.5mm | 1 | 1V2
TP5 | TestPoint_Pad_D1.5mm | 1 | BI
TP6 | TestPoint_Pad_D1.5mm | 1 | RST_N
TP9 | TestPoint_Pad_D1.5mm | 1 | ROSC_SEL
U10 | ESP32-S3-WROOM-1U | 1 | ESP32-S3-WROOM-1
U11 | TSSOP-8_3x3mm_P0.65mm | 1 | EMC2101
U12 | LQFN40-CLIP | 1 | TPS546D24ARVFR
U2 | Crystal_SMD_2016-4Pin_2.0x1.6mm | 1 | 25MHz
U3 | SOT-23-5 | 1 | TLV75712PDBV
U4 | SOT-23-5 | 1 | MCP1824T-0802E
U5 | BM1370 | 1 | BM1370_mode1
U6, U7, U8 | SOT-23-6_Handsoldering | 3 | SN74LVC1T45DBV
U9 | SOT-23-5 | 1 | TLV75733PDBV

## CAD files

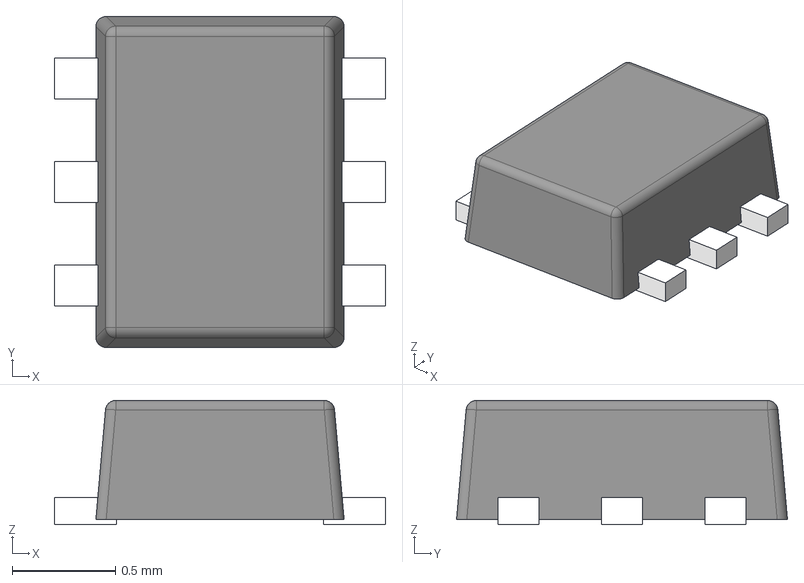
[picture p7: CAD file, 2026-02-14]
kicad/3d/DRL0006A.stp
1.60 x 1.60 x 0.6 mm
FRAME-DRL0006A
BODY-SOT
PIN1-ID

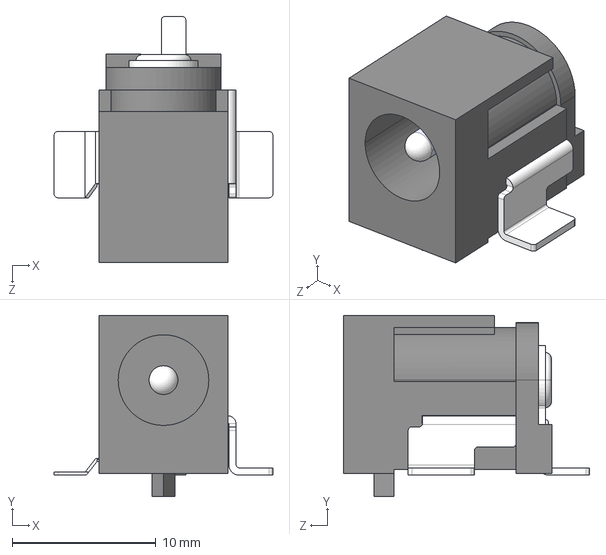
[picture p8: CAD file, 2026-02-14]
kicad/3d/CUI_DEVICES_PJ-036AH-SMT-TR.step
15.2 x 12.6 x 17.1 mm

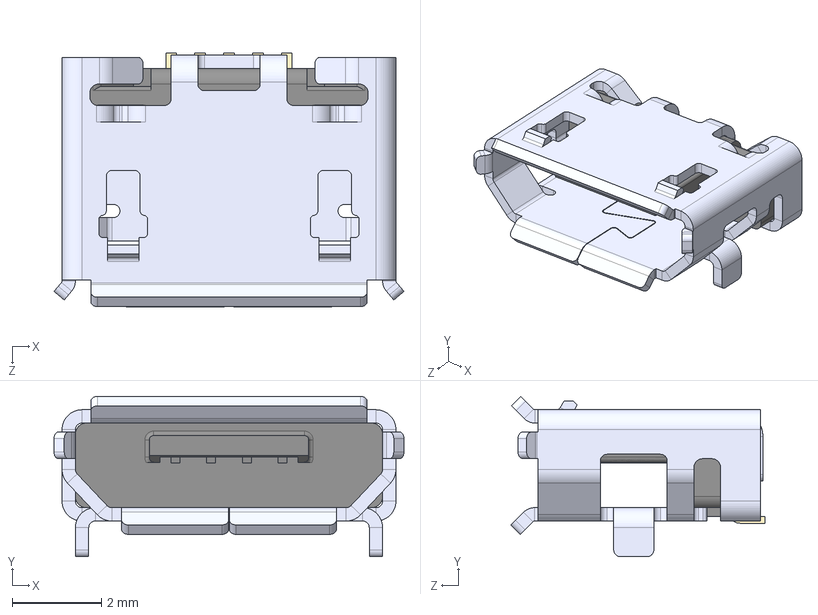
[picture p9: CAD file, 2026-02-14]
kicad/3d/USB_10118193-0001LF.STEP
7.86 x 3.60 x 5.71 mm

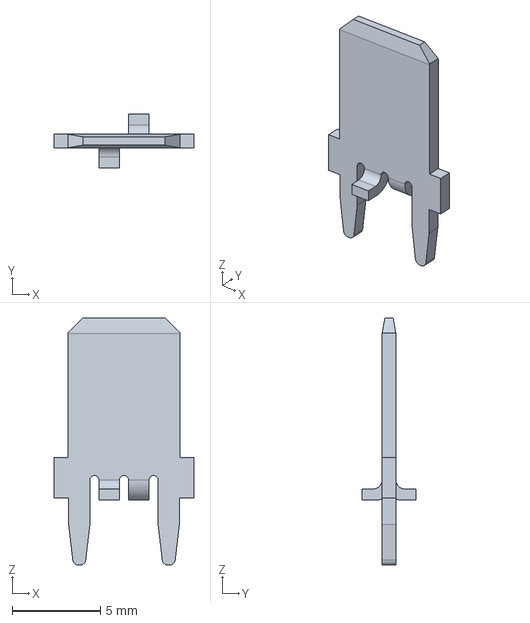
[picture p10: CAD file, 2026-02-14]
kicad/3d/c-63862-1-r-3d.stp
7.92 x 3.07 x 14.0 mm

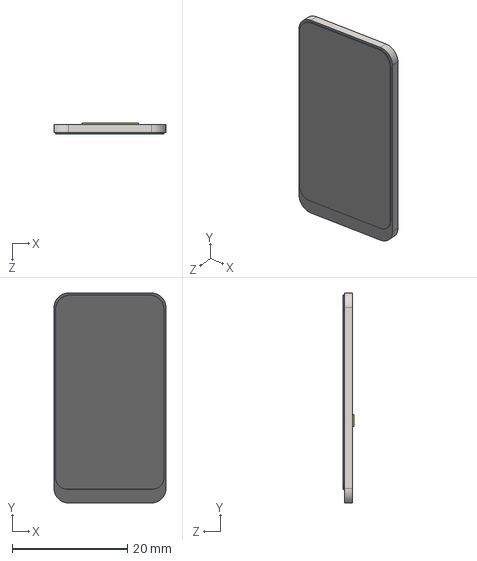
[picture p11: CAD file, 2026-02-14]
kicad/3d/DISST7789-176x320.STEP
19.4 x 36.4 x 1.86 mm

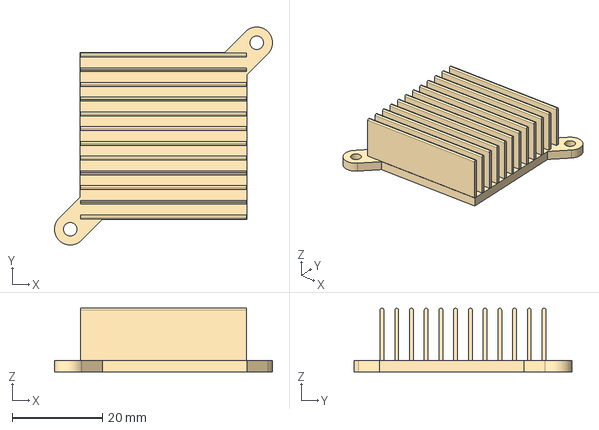
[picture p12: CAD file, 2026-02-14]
kicad/3d/Bitaxe_Heatsink.step
48.4 x 48.4 x 14.1 mm

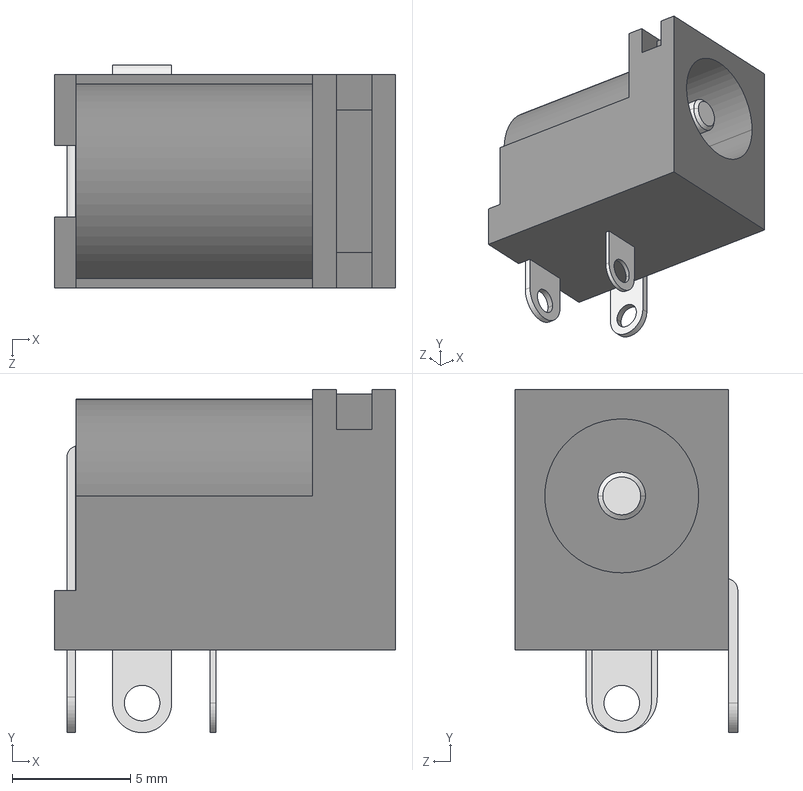
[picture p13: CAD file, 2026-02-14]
kicad/3d/CUI_DEVICES_PJ-002AH.step
14.4 x 14.5 x 9.40 mm

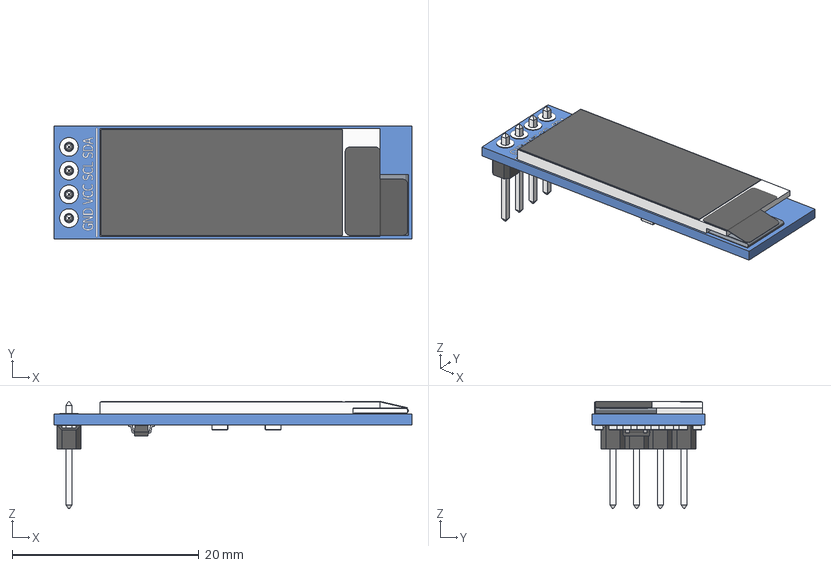
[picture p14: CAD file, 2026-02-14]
kicad/3d/OLED_0.91_128x32.stp
38.3 x 12.1 x 11.5 mm
OLED_0.91_128x32
Pin Header 4 x 1 TH 2.54mm Pitch
RESC-0603 x 13
2SD0601A

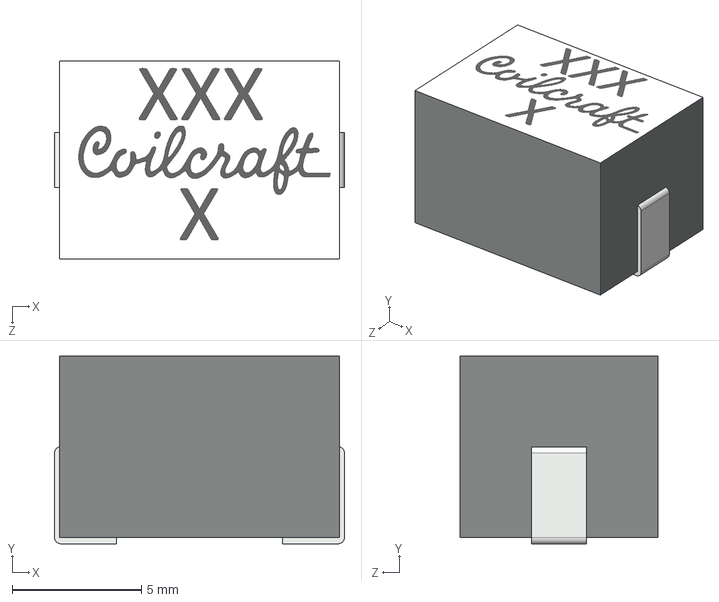
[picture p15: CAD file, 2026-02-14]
kicad/3d/Coilcraft-SLC1175.STEP
11.2 x 7.25 x 7.65 mm

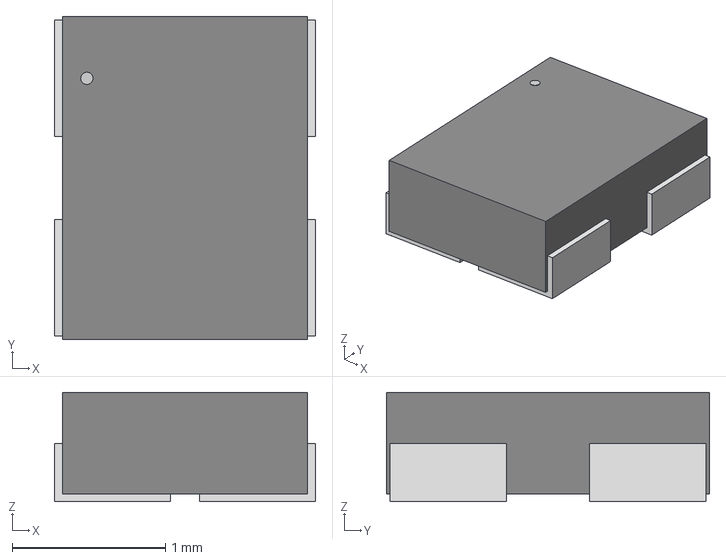
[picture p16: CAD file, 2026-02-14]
kicad/3d/XRCGB27M120F3M10R0_MUR.step
1.70 x 2.11 x 0.714 mm

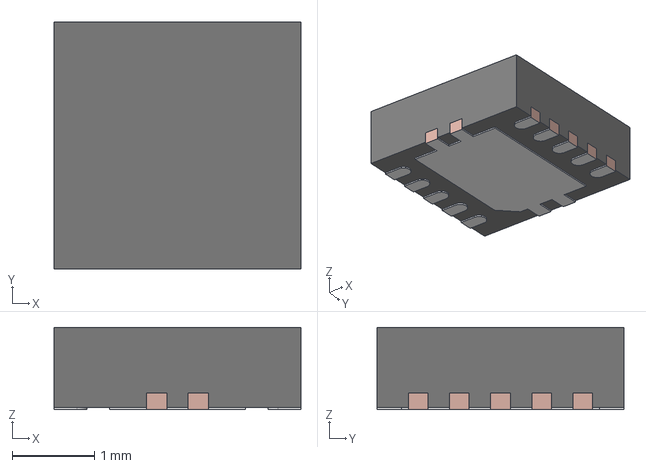
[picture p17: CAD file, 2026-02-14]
kicad/3d/DRC0010J.stp
3.00 x 3.00 x 1.00 mm
BODY-SON
FRAME-DRC0010J

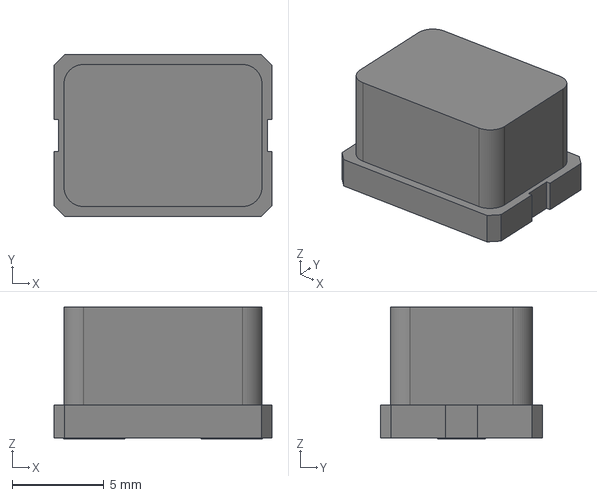
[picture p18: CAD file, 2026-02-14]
kicad/3d/SLC1175-271MEC_COC.step
11.9 x 8.83 x 7.19 mm

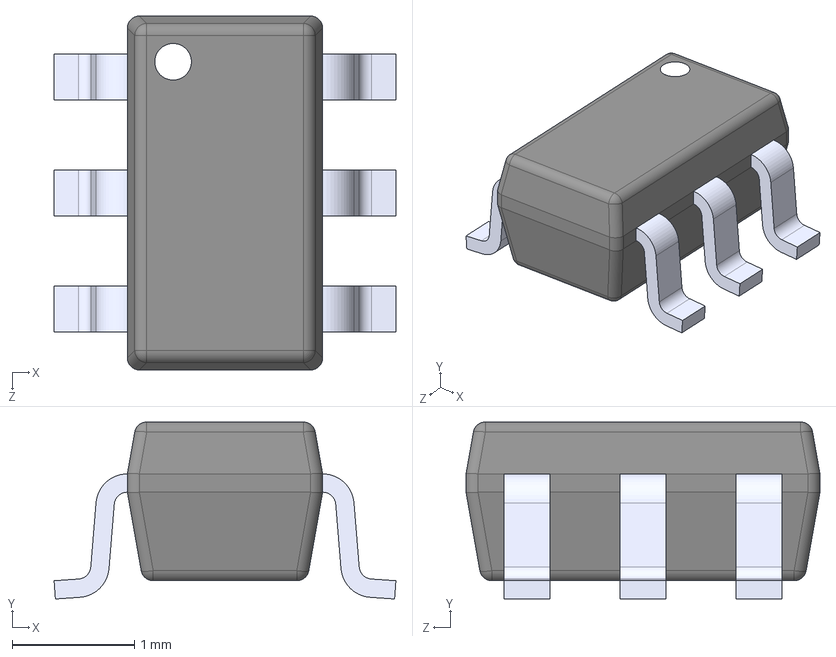
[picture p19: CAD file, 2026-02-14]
kicad/3d/SN74AXC1T45DBVR.STEP
2.80 x 1.45 x 2.90 mm

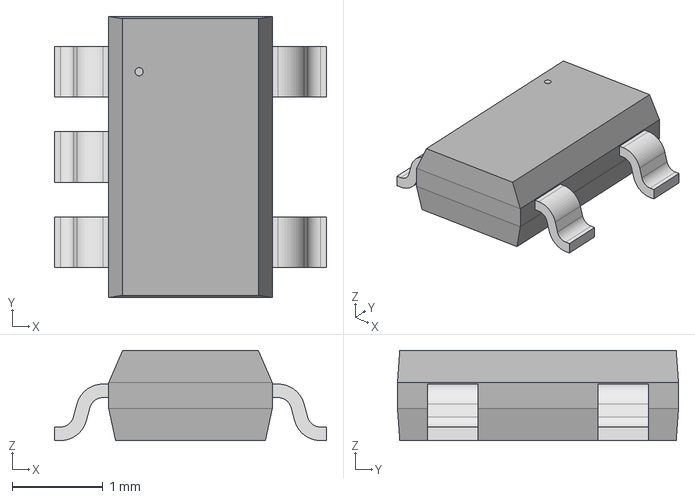
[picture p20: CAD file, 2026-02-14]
kicad/3d/TSOT-23-5_RIT.step
3.00 x 3.10 x 0.993 mm

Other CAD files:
kicad/3d/Cree_PLCC6.stp
kicad/3d/PLCC6_LED_3_5X3_4X2_8_CRW.step
kicad/3d/2R5TPE220MAFB.step
kicad/3d/XTAL_SC32S-7PF20PPM_EPS.step
kicad/3d/21-0164B_L622-1_MXM.step
kicad/3d/470531000.stp
kicad/3d/54-00164.STEP
kicad/3d/BM04B-SRSS-TBT(LF)(SN)--3DModel-STEP-56544.STEP
kicad/3d/BM1368xx.stp
kicad/3d/CS1213AG-tr.stp
kicad/3d/CUI_DEVICES_PJ-037AH.step
kicad/3d/CX3225SB16000H0FLJCC.STEP
kicad/3d/DQG0008A.stp
kicad/3d/DQH0008A.stp
kicad/3d/ESP32-S3-WROOM-1-N8R2--3DModel-STEP-56544.STEP
kicad/3d/FP1006V2-R.STEP
kicad/3d/FTSH-105-01-F-DV-K.stp
kicad/3d/IHLP2020CZ.step
kicad/3d/SMV_z90.stp
kicad/3d/SOT-23-5_M5_MCH.step
kicad/3d/ST-4ETB2k_(202).stp
kicad/3d/SW_CS1213AGF260_CRS.step
kicad/3d/TPS546D24ARVFR.step
kicad/3d/TXB0104RGYR.STEP
kicad/3d/oscillator3.2x2.5.step

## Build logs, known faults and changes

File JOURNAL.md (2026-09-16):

---
title: BitcoinMiner
author: sneakylizard123-4
description: A BM1370 bitcoin mining board
created_at: 2026-02-14
---

# February 14

Started the BitcoinMiner project. I wanted a single-board miner with everything on one PCB:
- Asic
- Wifi
- Fan
- Power

Picked the BM1370 over the BM1368 for the better efficiency and because secondary market pricing has come down.

Split the schematic into hierarchical subsheets (BM1370, Power, ESP32, Fan) and imported the footprints and symbols from the bitaxe gamma library since KiCad had nothing for the ASIC.

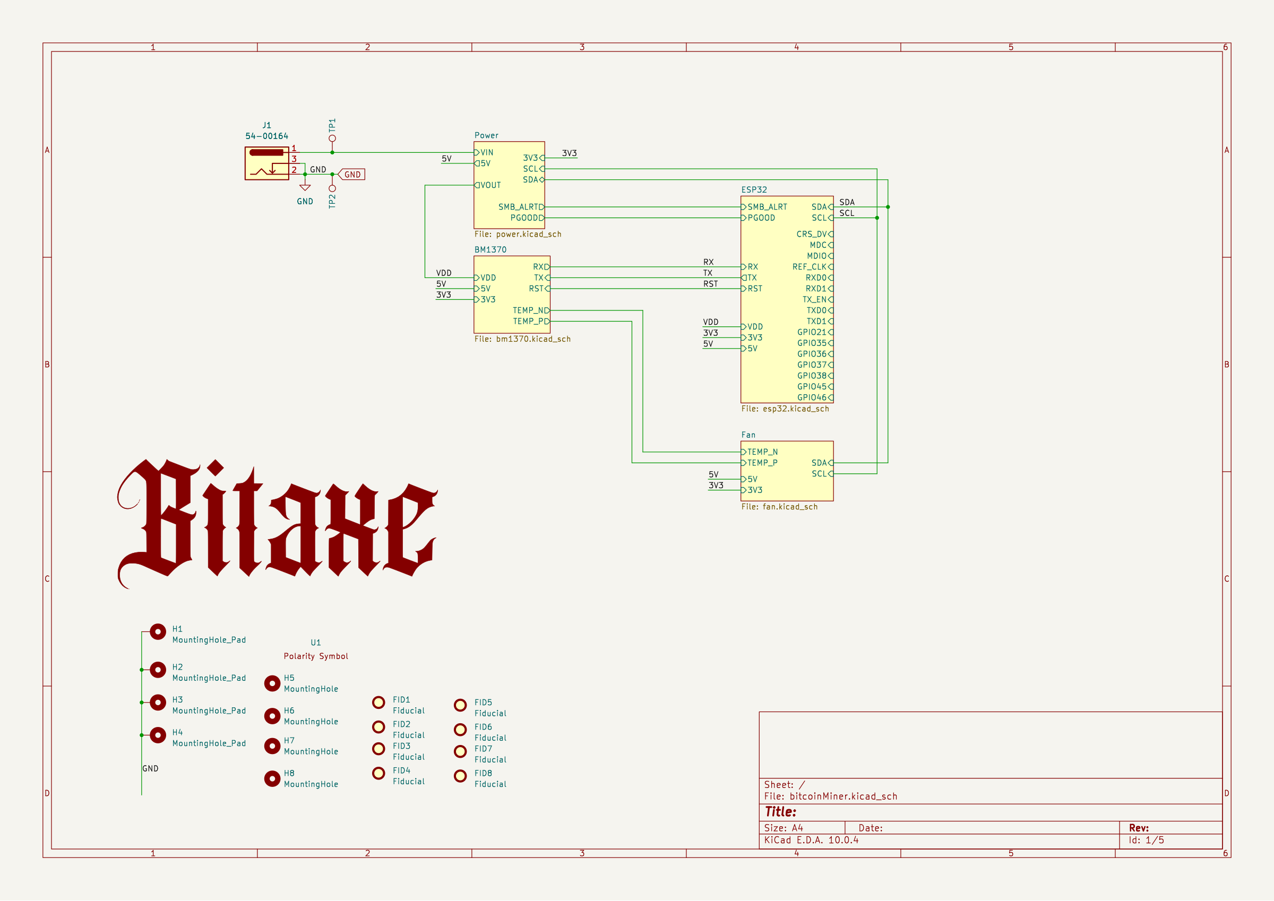
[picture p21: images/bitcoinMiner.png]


**Total Time Spent: 5 hours**

# February 15

Added the Ethernet and fan subsheets, then started the first PCB pass. Used three level translators to step the 1.2V ASIC signals up to the ESP32's 3.3V. Ethernet would end up being removed later, even though i put a lot of effort into it.

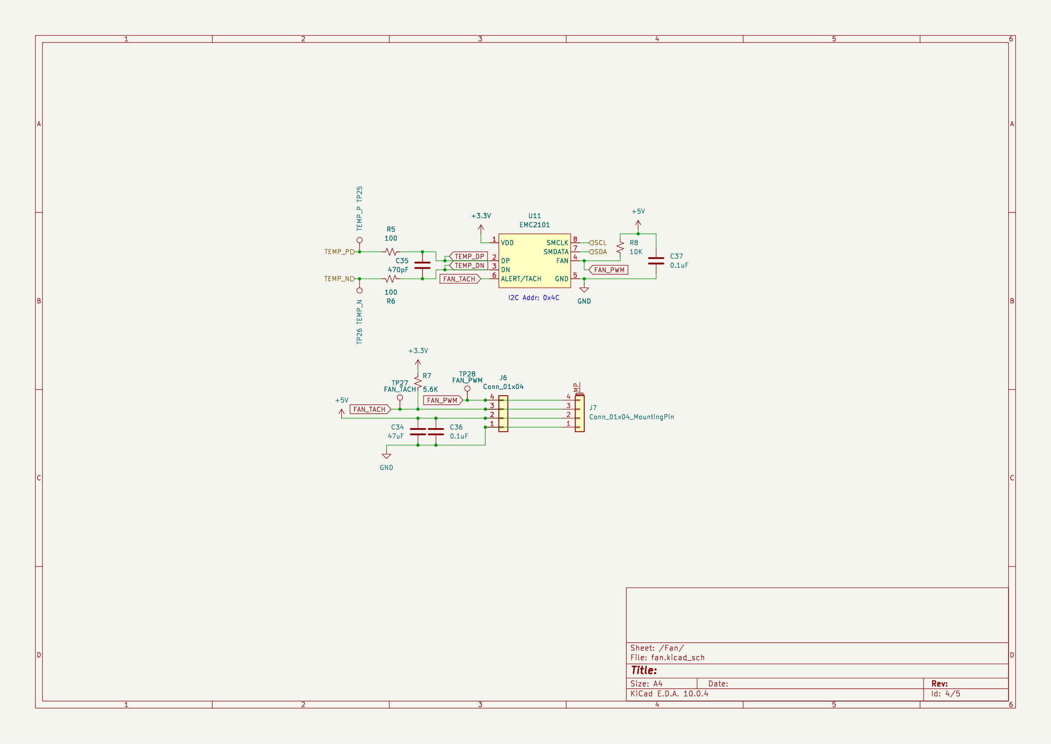
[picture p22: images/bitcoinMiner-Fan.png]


**Total Time Spent: 7 hours**

# February 16

Grinded on routing the Ethernet PHY and the power section. The inductor placement kept ending up too far from the output caps..

Routed the 1.2V rail as a solid copper pour across two layers to keep voltage drop in check for the 15A the ASIC draws at full hash rate.

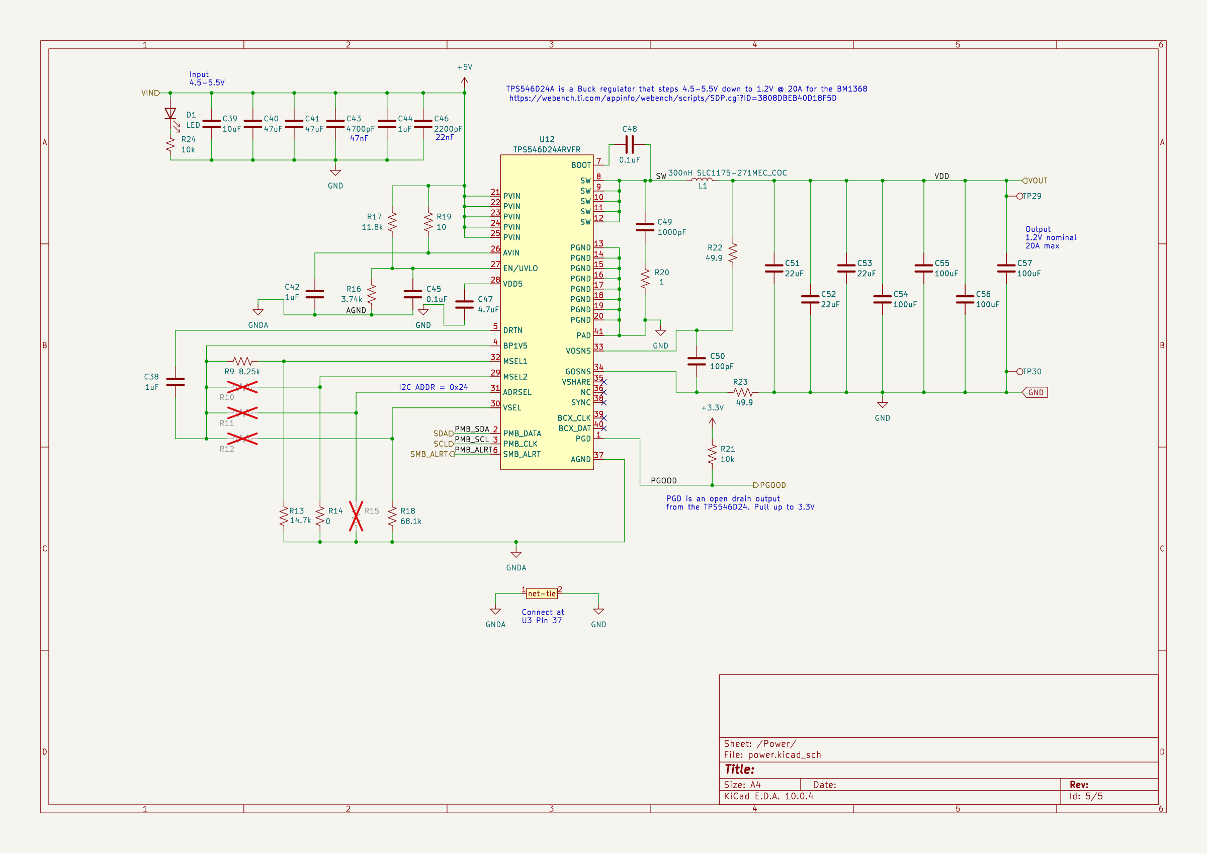
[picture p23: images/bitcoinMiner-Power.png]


**Total Time Spent: 6 hours**

# February 17

Eight hours finishing the first routing pass.
Placed the fan controller close to the ASIC so the remote temperature diode traces stay short.
The decoupling caps around the BM1370 took the longest because there are so many

Added mounting holes and fiducials for pick-and-place. The board was fully connected by the end, with 30 DRC issues.

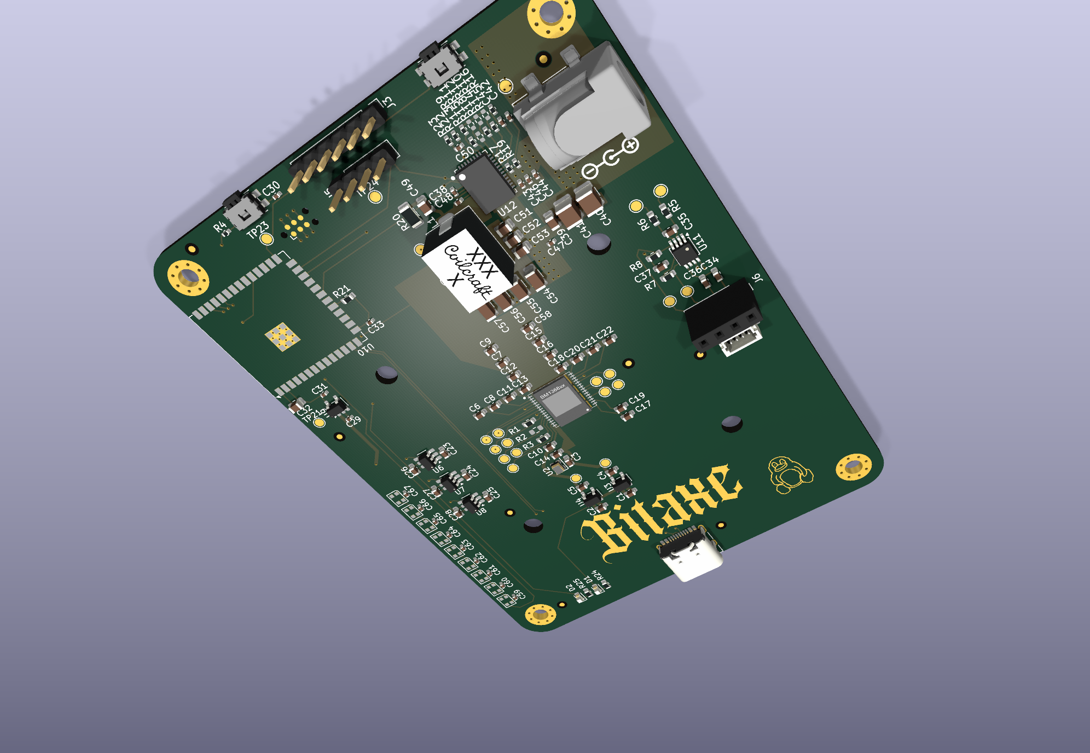
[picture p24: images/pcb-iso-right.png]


**Total Time Spent: 8 hours**

# February 20

Fixed all 30 DRC violations.
Most were at the USB-C connector where the pads are very tight.
cut a relief in the ground pour around it to give the data traces room.
The barrel jack had the wrong footprint, switched it to a different outline. 
Caught two traces on the wrong layer that would have shorted to the power plane.



**Total Time Spent: 4 hours**

# February 22

Reworked the power section.
Moved the inductor 2mm closer to the output caps, widened the pour and added ground vias under it
parasitic inductance dropped from 1nH to ~0.5nH and simulated ripple from 40mV to 18mV.
Bumped the bulk caps up to 100uF.

Added the bitcoin logo to the silkscreen.



**Total Time Spent: 3 hours**

# March 8-9

Re-ran DRC after a few weeks away and stitched up some ground pour that had fragmented during the power rework.
Reorganized the repo:
- KiCad files moved into `kicad/`
- 3D STEP files into `kicad/3d/`
- accumulated KiCad backup zips got deleted.

**Total Time Spent: 6 hours**

# August 12

Finished the schematic after a long break.
Connected the remaining ESP32 GPIO breakout headers
set proper USB CC resistor values
ran ERC across all the sheets
Added a .gitignore
Found a duplicate C58 reference and standardized the net labels to match the bitaxe naming conventions.
Started the readme.

**Total Time Spent: 4 hours**

# August 13

Finished the readme and added the WS2812B status LED chain. First time using `kicad-cli pcb render` instead of Blender, it ray-traces all the board angles in about 30 seconds each.



**Total Time Spent: 5 hours**

# August 16

Removed Ethernet.
ethernet stuff ate 15% of the board for a feature WiFi already covers
also it was my first time using Ethernet in a project.
Dropped the subsheet, cleaned up the dangling nets.
rerouted the power section with the freed-up space. 
The schematic has four subsheets instead of five.

maybe i'l make an ethernet project soon?

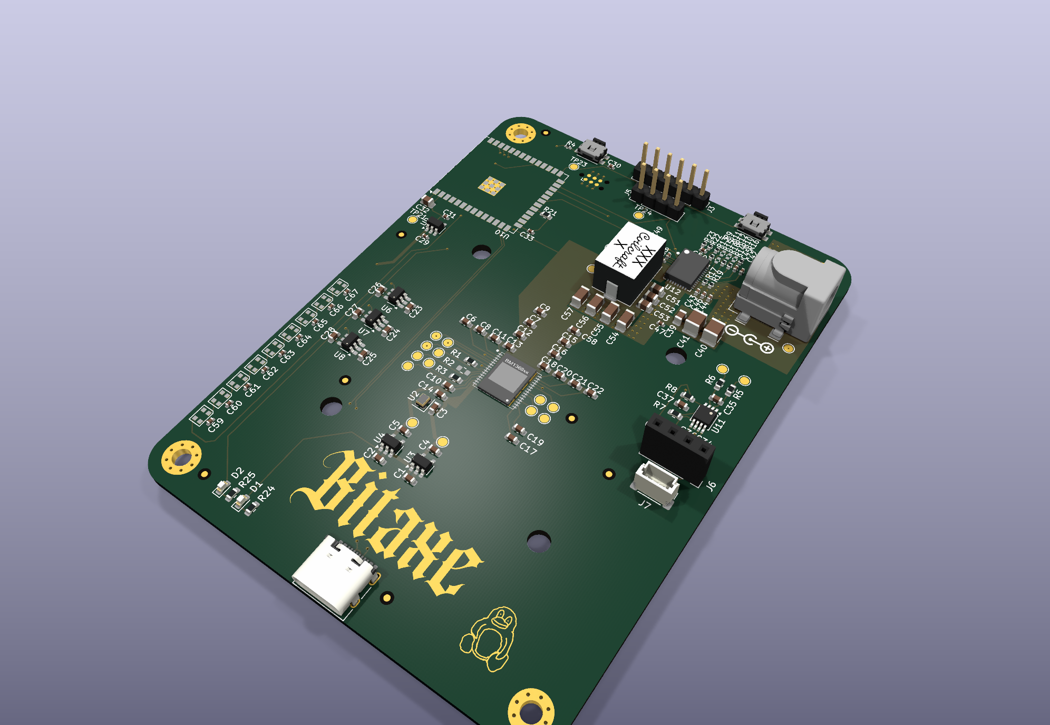
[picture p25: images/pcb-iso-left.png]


**Total Time Spent: 3 hours**

# September 5

Decided to finish the board before school.
Annotated the entire schematic, routed the PCB better to handle the high currents the ASIC needs, and beefed up all the power rails.
Added logos and a few easter eggs hidden in the board. Board is 100x75mm, 4-layer FR4.

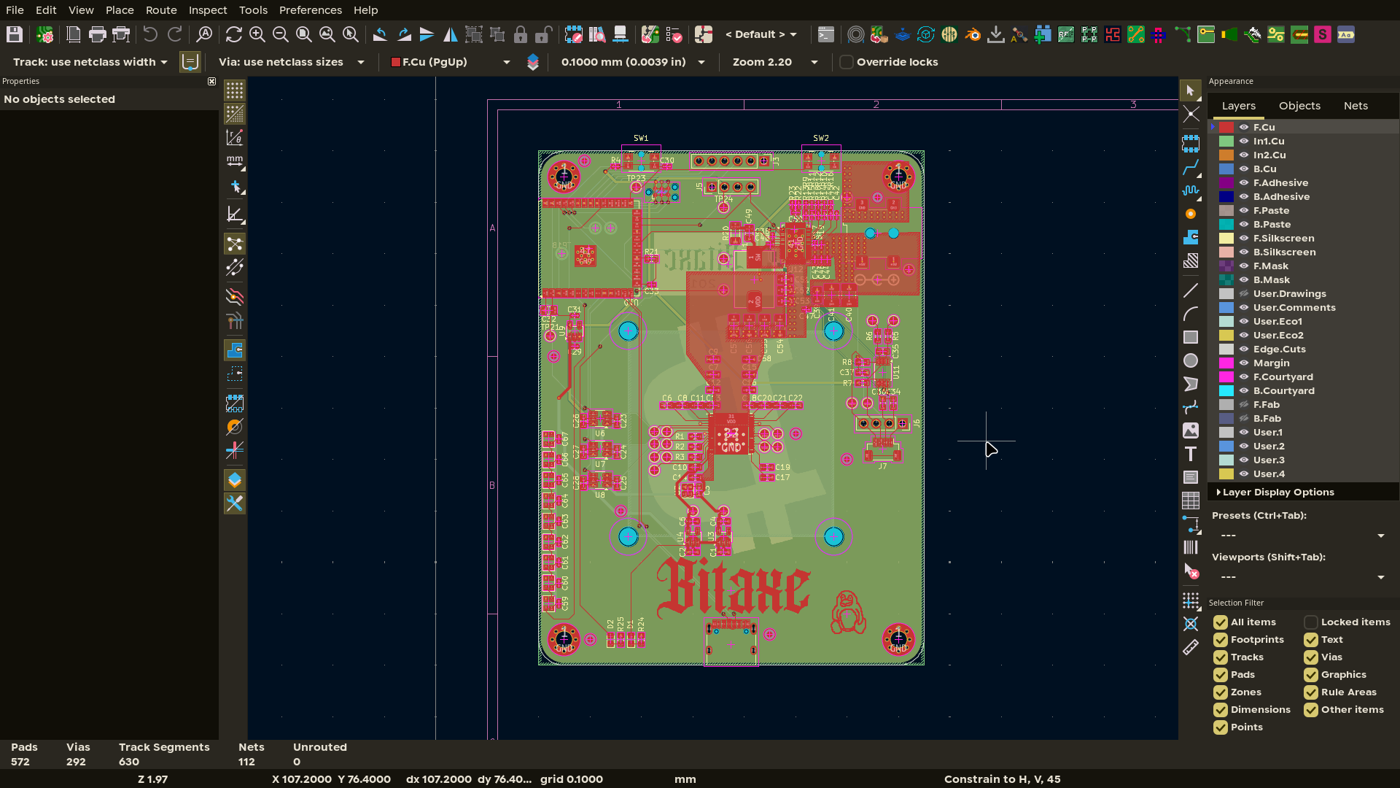
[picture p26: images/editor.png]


# September 16

Put together the order - filled in LCSC part numbers and links for every line item in the BOM. Built the firmware: vendored bitaxe's ESP-Miner into `firmware/` and added a "bitcoinMiner" board target (ESP32-S3, BM1370, 525MHz) with its own config CSV. Flashing and pin docs live in `firmware/README.md`.



**Total Time spent: 3 hours**

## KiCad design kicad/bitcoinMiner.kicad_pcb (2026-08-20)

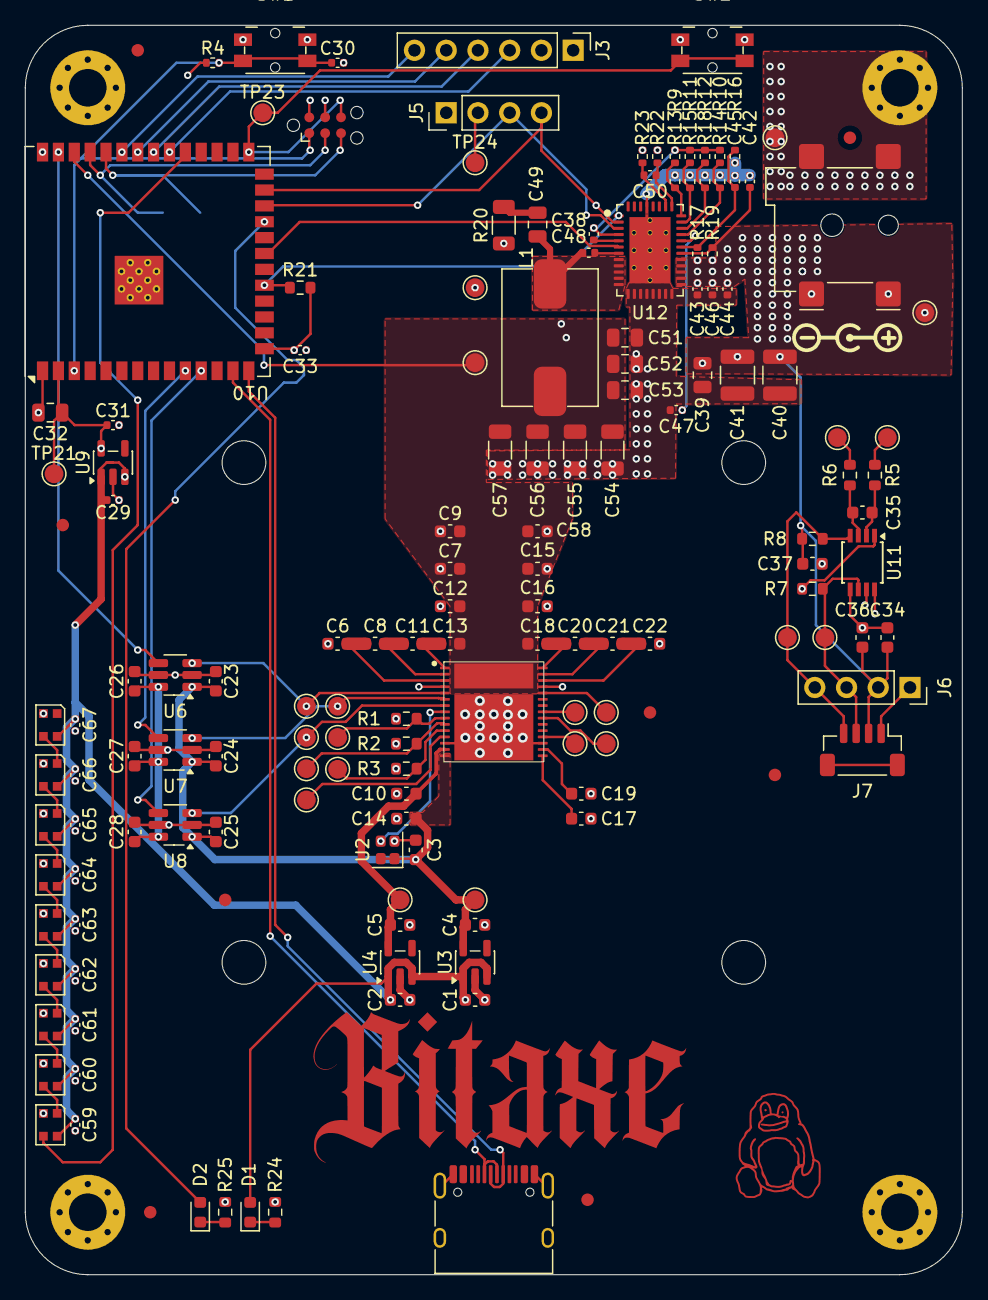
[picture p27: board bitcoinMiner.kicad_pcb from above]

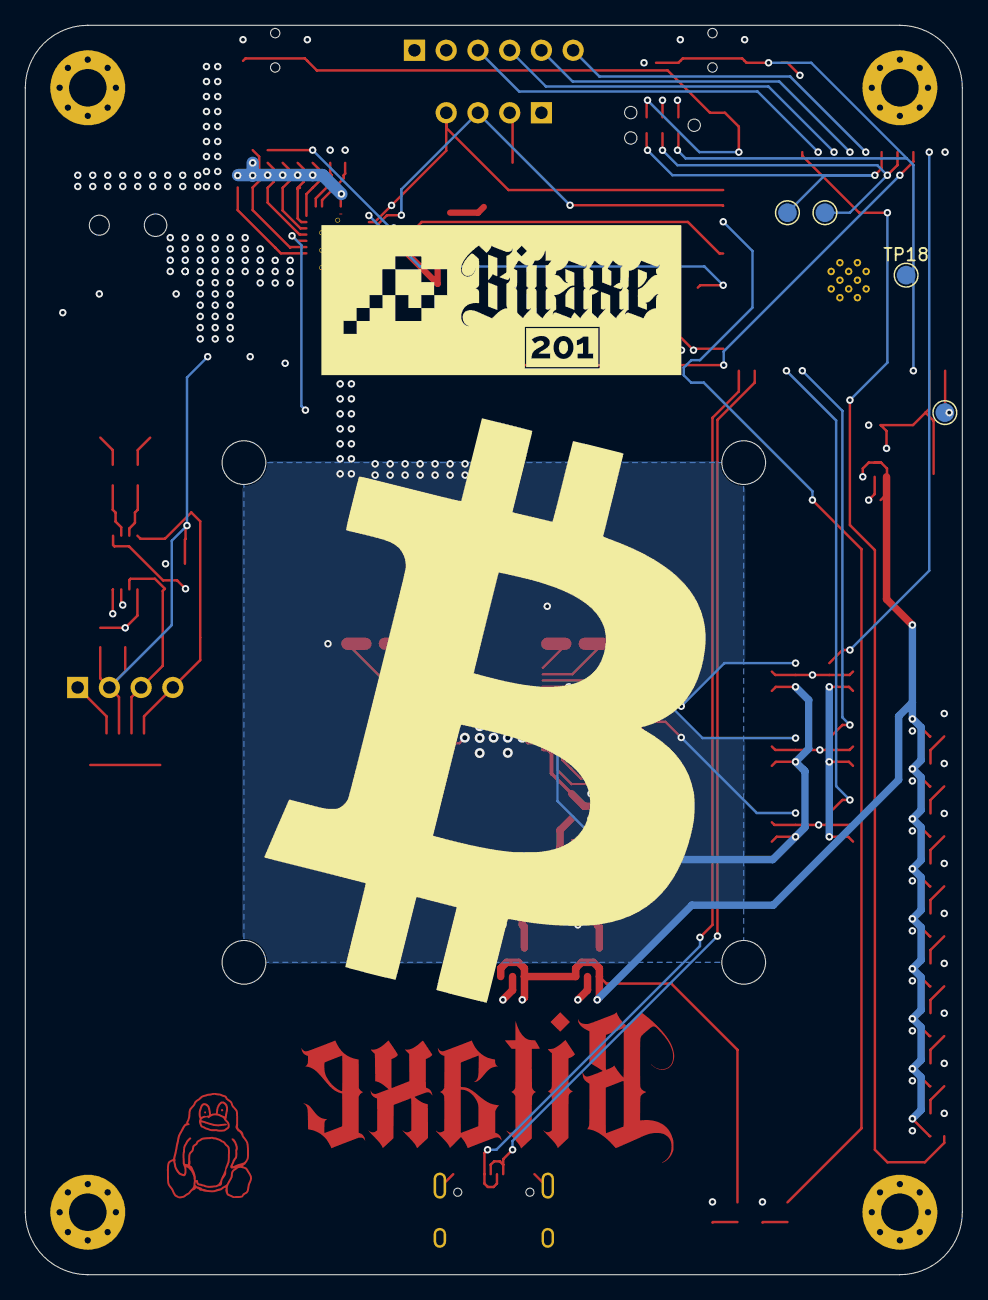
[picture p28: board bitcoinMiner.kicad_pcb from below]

Board: 4 copper layers, 75.0 x 100.0 mm, 170 parts (4 on the bottom side), 76 nets.

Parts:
C1, C2, C4, C5, C6, C7, C8, C9, C10, C11, C12, C13, C14, C15, C16, C17, C18, C19, C20, C21, C22, C58: 1uF; C_0603_1608Metric
C3, C23, C24, C25, C26, C27, C28, C36, C37: 0.1uF; C_0603_1608Metric
C29, C30, C31, C38, C42, C44: 1uF; C_0402_1005Metric
C32, C39: 10uF; C_0805_2012Metric
C33, C45, C48, C59, C60, C61, C62, C63, C64, C65, C66, C67: 0.1uF; C_0402_1005Metric
C34: 47uF; C_0603_1608Metric
C35: 470pF; C_0603_1608Metric
C40, C41: 47uF; C_1210_3225Metric
C43: 4700pF; C_0402_1005Metric
C46: 2200pF; C_0402_1005Metric
C47: 4.7uF; C_0402_1005Metric
C49: 1000pF; C_0805_2012Metric
C50: 100pF; C_0402_1005Metric
C51, C52, C53: 22uF; C_0805_2012Metric
C54, C55, C56, C57: 100uF; C_1206_3216Metric
D1, D2: LED; LED_0603_1608Metric
D3, D4, D5, D6, D7, D8, D9, D10, D11: WS2812B-2020; LED_WS2812B-2020_PLCC4_2.0x2.0mm
FID1, FID2, FID3, FID4, FID5, FID6, FID7, FID8: Fiducial; Fiducial_1mm_Mask2mm
H1, H2, H3, H4: MountingHole_Pad; MountingHole_3mm_Pad_Via
H5, H6, H7, H8: MountingHole; MountingHole_3.5mm
J1: 54-00164; BarrelJack_Wuerth_694106106102_2.0x5.5mm
J2: TC2030-IDC; Tag-Connect_TC2030-IDC-NL_2x03_P1.27mm_Vertical
J3: Conn_01x06; PinHeader_1x06_P2.54mm_Vertical
J4: USB_C_Receptacle_USB2.0_14P; USB_C_Receptacle_HRO_TYPE-C-31-M-12
J5: Conn_01x04; PinHeader_1x04_P2.54mm_Vertical
J6: Conn_01x04; PinSocket_1x04_P2.54mm_Vertical
J7: Conn_01x04_MountingPin; JST_SH_BM04B-SRSS-TB_1x04-1MP_P1.00mm_Vertical
L1: 300nH SLC1175-271MEC_COC; L_Coilcraft_SLC1175
R1, R2, R3: 1K; R_0603_1608Metric
R4: 10k; R_0402_1005Metric
R5, R6: 100; R_0603_1608Metric
R7: 5.6K; R_0603_1608Metric
R8: 10K; R_0603_1608Metric
R9: 8.25k; R_0402_1005Metric
R10, R11, R12, R15: R_0402_1005Metric
R13: 14.7k; R_0402_1005Metric
R14: 0; R_0402_1005Metric
R16: 3.74k; R_0402_1005Metric
R17: 11.8k; R_0402_1005Metric
R18: 68.1k; R_0402_1005Metric
R19: 10; R_0402_1005Metric
R20: 1; R_1206_3216Metric
R21, R24, R25: 10k; R_0603_1608Metric
R22, R23: 49.9; R_0402_1005Metric
SW1, SW2: SW_Push; Panasonic_EVQPUM_EVQPUD
T1: net-tie; NetTie-0.25mm
TP1, TP2, TP18, TP19, TP20, TP21, TP22, TP23, TP24, TP29, TP30: TestPoint; TestPoint_Pad_D1.5mm
TP3: 0V8; TestPoint_Pad_D1.5mm
TP4: 1V2; TestPoint_Pad_D1.5mm
TP5: BI; TestPoint_Pad_D1.5mm
TP6: RST_N; TestPoint_Pad_D1.5mm
TP9: ROSC_SEL; TestPoint_Pad_D1.5mm
TP10: LITE_PAD; TestPoint_Pad_D1.5mm
TP11: INV_CLKO; TestPoint_Pad_D1.5mm
TP12: NRSTO; TestPoint_Pad_D1.5mm
TP13: CO; TestPoint_Pad_D1.5mm
TP14: RI; TestPoint_Pad_D1.5mm
TP15: CLKO; TestPoint_Pad_D1.5mm
TP16: BO; TestPoint_Pad_D1.5mm
TP17: PIN_MODE; TestPoint_Pad_D1.5mm
TP25: TEMP_P; TestPoint_Pad_D1.5mm
TP26: TEMP_N; TestPoint_Pad_D1.5mm
TP27: FAN_TACH; TestPoint_Pad_D1.5mm
TP28: FAN_PWM; TestPoint_Pad_D1.5mm
U1: polarity
U2: 25MHz; Crystal_SMD_2016-4Pin_2.0x1.6mm
U3: TLV75712PDBV; SOT-23-5
U4: MCP1824T-0802E; SOT-23-5
U5: BM1370_mode1; BM1370
U6, U7, U8: SN74LVC1T45DBV; SOT-23-6_Handsoldering
U9: TLV75733PDBV; SOT-23-5
U10: ESP32-S3-WROOM-1; ESP32-S3-WROOM-1U
U11: EMC2101; TSSOP-8_3x3mm_P0.65mm
U12: TPS546D24ARVFR; LQFN40-CLIP

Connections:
0V8: C5.1, C10.1, TP3.1 (1_1), U4.5 (VOUT), U5.14 (VDDIO_08_0)
+1V2: C3.1, C4.1, C14.1, C23.1, C24.1, C25.1, TP4.1 (1_1), U2.1 (EN), U2.4 (VIN), U3.5 (OUT), U5.15 (VDDIO_12_0), U6.1 (VCCA), U7.1 (VCCA), U8.1 (VCCA)
+3.3V: C26.1, C27.1, C28.1, C31.1, C32.1, C33.1, J2.2, J5.2, R4.1, R7.2, R21.2, TP21.1 (1_1), TP24.1 (1_1), U6.6 (VCCB), U7.6 (VCCB), U8.6 (VCCB), U9.5 (OUT), U10.2 (3V3), U10.15 (IO3), U11.1 (VDD)
+5V: C1.1, C2.1, C29.1, C34.1, C36.1, C37.1, C39.1, C40.1, C41.1, C43.1, C44.1, C46.1, C59.1, C60.1, C61.1, C62.1, C63.1, C64.1, C65.1, C66.1, C67.1, D1.2 (A), D3.4 (VDD), D4.4 (VDD), D5.4 (VDD), D6.4 (VDD), D7.4 (VDD), D8.4 (VDD), D9.4 (VDD), D10.4 (VDD), D11.4 (VDD), J1.1, J3.1, J6.2, J7.2, R8.1, R17.1, R19.1, TP1.1 (1_1), U3.1 (IN), U3.3 (EN), U4.1 (VIN), U4.3 (EN), U9.1 (IN), U9.3 (EN), U12.21 (PVIN), U12.22 (PVIN), U12.23 (PVIN), U12.24 (PVIN), U12.25 (PVIN)
/ESP32/EN: C30.1, J2.1, R4.2, SW1.2, TP18.1 (1_1), U10.3 (EN)
/ESP32/IO0: J2.6, SW2.2, TP23.1 (1_1), U10.27 (IO0)
/ESP32/P_RX: J2.5, TP20.1 (1_1), U10.36 (RXD0)
/ESP32/P_TX: J2.3, TP19.1 (1_1), U10.37 (TXD0)
/ESP32/USB_D+: J4.A6 (D+), J4.B6 (D+), U10.14 (USB_D+)
/ESP32/USB_D-: J4.A7 (D-), J4.B7 (D-), U10.13 (USB_D-)
/Fan/TEMP_N: R6.1, TP26.1 (1_1)
/Fan/TEMP_P: R5.1, TP25.1 (1_1)
/Power/PGOOD: R21.1, U10.19 (IO11), U12.1 (PGD)
/Power/PMB_ALRT: U10.21 (IO13), U12.6 (SMB_ALRT)
/Power/SW: C48.2, C49.2, L1.1, U12.8 (SW), U12.9 (SW), U12.10 (SW), U12.11 (SW), U12.12 (SW)
/SCL: J5.3, U10.24 (IO47), U11.8 (SMCLK), U12.3 (PMB_CLK)
/SDA: J5.4, U10.25 (IO48), U11.7 (SMDATA), U12.2 (PMB_DATA)
/VDD: C7.2, C9.2, C12.2, C13.2, C15.2, C16.2, C18.1, C51.1, C52.1, C53.1, C54.1, C55.1, C56.1, C57.1, C58.2, L1.2, R22.1, TP29.1 (1_1), U5.31 (VDD), U10.38 (IO2)
BI: R1.2, TP5.1 (1_1), U5.9 (BI)
BO: TP16.1 (1_1), U5.22 (BO)
CI: TP13.1 (1_1), U5.6 (CI), U7.3 (A)
CLKI: U2.3 (OUT), U5.8 (CLKI)
CLKO: TP15.1 (1_1), U5.23 (CLKO)
FAN_PWM: J6.4, J7.4, R8.2, TP28.1 (1_1), U11.4 (FAN)
FAN_TACH: J6.3, J7.3, R7.1, TP27.1 (1_1), U11.6 (ALERT/TACH)
GND: C1.2, C2.2, C3.2, C4.2, C5.2, C6.1, C7.1, C9.1, C10.2, C12.1, C14.2, C15.1, C16.1, C17.2, C19.2, C22.2, C23.2, C24.2, C25.2, C26.2, C27.2, C28.2, C29.2, C30.2, C31.2, C32.2, C33.2, C34.2, C36.2, C37.2, C39.2, C40.2, C41.2, C43.2, C44.2, C46.2, C47.2, C51.2, C52.2, C53.2, C54.2, C55.2, C56.2, C57.2, C58.1, C59.2, C60.2, C61.2, C62.2, C63.2, C64.2, C65.2, C66.2, C67.2, D3.2 (VSS), D4.2 (VSS), D5.2 (VSS), D6.2 (VSS), D7.2 (VSS), D8.2 (VSS), D9.2 (VSS), D10.2 (VSS), D11.2 (VSS), H1.1 (1_1), H2.1 (1_1), H3.1 (1_1), H4.1 (1_1), J1.2, J1.3, J2.4, J3.2, J4.A1 (GND), J4.A12 (GND), J4.B1 (GND), J4.B12 (GND), J4.SH (SHIELD), J5.1, J6.1, J7.1, R1.1, R2.1, R3.1, R20.1, R23.2, R24.2, R25.2, SW1.1, SW2.1, T1.2, TP2.1 (1_1), TP22.1 (1_1), TP30.1 (1_1), U2.2 (GND), U3.2 (GND), U4.2 (GND), U5.4 (VSS), U5.13 (PLL_VSS), U5.18 (VSS), U5.27 (VSS), U5.32 (VSS), U6.2 (GND), U6.5 (DIR), U7.2 (GND), U7.5 (DIR), U8.2 (GND), U8.5 (DIR), U9.2 (GND), U10.1 (GND), U10.40 (GND), U10.41 (GND), U11.5 (GND), U12.13 (PGND), U12.14 (PGND), U12.15 (PGND), U12.16 (PGND), U12.17 (PGND), U12.18 (PGND), U12.19 (PGND), U12.20 (PGND), U12.41 (PAD)
GNDA: C42.1, C45.2, R13.1, R14.2, R15.2, R16.2, R18.2, T1.1, U12.37 (AGND)
NRSTO: TP12.1 (1_1), U5.26 (NRSTO)
unnamed: C49.1, R20.2
unnamed: D1.1 (K), R24.1
unnamed: D2.2 (A), U10.23 (IO21)
unnamed: D2.1 (K), R25.1
unnamed: D3.3 (DIN), U10.31 (IO38)
unnamed: D3.1 (DOUT), D4.3 (DIN)
unnamed: D4.1 (DOUT), D5.3 (DIN)
unnamed: D5.1 (DOUT), D6.3 (DIN)
unnamed: D6.1 (DOUT), D7.3 (DIN)
unnamed: D7.1 (DOUT), D8.3 (DIN)
unnamed: D8.1 (DOUT), D9.3 (DIN)
unnamed: D9.1 (DOUT), D10.3 (DIN)
unnamed: D10.1 (DOUT), D11.3 (DIN)
unnamed: J3.3, U10.32 (IO39)
unnamed: J3.4, U10.33 (IO40)
unnamed: J3.5, U10.34 (IO41)
unnamed: J3.6, U10.35 (IO42)
unnamed: TP11.1 (1_1), U5.12 (INV_CLKO)
unnamed: R3.2, TP10.1 (1_1), U5.11 (LITE_PAD)
unnamed: R2.2, TP9.1 (1_1), U5.10 (ROSC_SEL)
unnamed: C6.2, C8.1, U5.3 (VDD1_0)
unnamed: C21.2, C22.1, U5.28 (VDD1_1)
unnamed: C8.2, C11.1, U5.2 (VDD2_0)
unnamed: C20.2, C21.1, U5.29 (VDD2_1)
unnamed: C11.2, C13.1, U5.1 (VDD3_0)
unnamed: C18.2, C20.1, U5.30 (VDD3_1)
unnamed: C19.1, U5.17 (VDDIO_08_1)
unnamed: C17.1, U5.16 (VDDIO_12_1)
unnamed: R11.2, R15.1, U12.31 (ADRSEL)
unnamed: C42.2, R19.2, U12.26 (AVIN)
unnamed: C48.1, U12.7 (BOOT)
unnamed: C38.2, R9.1, R10.1, R11.1, R12.1, U12.4 (BP1V5)
unnamed: C38.1, U12.5 (DRTN)
unnamed: C45.1, R16.1, R17.2, U12.27 (EN/UVLO)
unnamed: C50.2, R23.1, U12.34 (GOSNS)
unnamed: R9.2, R13.2, U12.32 (MSEL1)
unnamed: R10.2, R14.1, U12.29 (MSEL2)
unnamed: C47.1, U12.28 (VDD5)
unnamed: C50.1, R22.2, U12.33 (VOSNS)
unnamed: R12.2, R18.1, U12.30 (VSEL)
PIN_MODE: TP17.1 (1_1), U5.19 (PIN_MODE)
RO: TP14.1 (1_1), U5.7 (RO), U8.3 (A)
RST: U6.4 (B), U10.39 (IO1)
RST_N: TP6.1 (1_1), U5.5 (NRSTI), U6.3 (A)
RX: U8.4 (B), U10.11 (IO18)
TEMP_DN: C35.2, R6.2, U11.3 (DN)
TEMP_DP: C35.1, R5.2, U11.2 (DP)
TX: U7.4 (B), U10.10 (IO17)

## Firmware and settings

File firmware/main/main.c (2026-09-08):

#include <stdlib.h>

#include "esp_event.h"
#include "esp_log.h"
#include "esp_psram.h"
#include "esp_heap_caps.h"
#include "cJSON.h"

#include "asic_result_task.h"
#include "create_jobs_task.h"
#include "hashrate_monitor_task.h"
#include "fan_controller_task.h"
#include "statistics_task.h"
#include "global_state.h"
#include "system.h"
#include "http_server.h"
#include "protocol_coordinator.h"
#include "i2c_bitaxe.h"
#include "adc.h"
#include "nvs_config.h"
#include "self_test.h"
#include "asic.h"
#include "bap/bap.h"
#include "device_config.h"
#include "connect.h"
#include "asic_reset.h"
#include "asic_init.h"
#include "task_monitor.h"
#include "filesystem.h"
#include "log_buffer.h"
#include "setup_ble.h"
#include "esp_ota_ops.h"

static GlobalState GLOBAL_STATE;

static const char * TAG = "bitaxe";

#define DEFAULT_GPIO_I2C_SDA CONFIG_GPIO_I2C_SDA
#define DEFAULT_GPIO_I2C_SCL CONFIG_GPIO_I2C_SCL

static void heap_alloc_failed_hook(size_t requested_size, uint32_t caps, const char *function_name)
{
    if (caps & MALLOC_CAP_SPIRAM) {
        ESP_EARLY_LOGE(TAG, "%s failed to allocate %zu bytes from PSRAM", function_name, requested_size);
        abort();
    }
}

static void *cjson_malloc_psram(size_t size)
{
    if (esp_psram_is_initialized()) {
        return heap_caps_malloc(size, MALLOC_CAP_SPIRAM);
    }
    return malloc(size);
}

static void cjson_free_psram(void *ptr)
{
    free(ptr);
}

void app_main(void)
{
    ESP_ERROR_CHECK(heap_caps_register_failed_alloc_callback(heap_alloc_failed_hook));

    cJSON_Hooks hooks = {
        .malloc_fn = cjson_malloc_psram,
        .free_fn = cjson_free_psram
    };
    cJSON_InitHooks(&hooks);
    if (esp_psram_is_initialized()) {
        GLOBAL_STATE.psram_is_available = true;
        log_buffer_init();
    } else {
        ESP_LOGE(TAG, "No PSRAM available on ESP32 device!");
    }

    ESP_LOGI(TAG, "Welcome to the bitaxe - FOSS || GTFO!");

    if (xTaskCreateWithCaps(cpu_monitor_task, "cpu_monitor", 4096, (void *)&GLOBAL_STATE, 1, NULL, MALLOC_CAP_SPIRAM) != pdPASS) {
        ESP_LOGE(TAG, "Error creating cpu monitor task");
    }
#ifdef CONFIG_ENABLE_TASK_MONITOR
    if (xTaskCreateWithCaps(task_monitor_task, "task_monitor", 8192, NULL, 1, NULL, MALLOC_CAP_SPIRAM) != pdPASS) {
        ESP_LOGE(TAG, "Error creating task monitor task");
    }
#endif
  
    // Initialize RST pin to low early to minimize ASIC power consumption
    ESP_ERROR_CHECK(asic_hold_reset_low());
    ESP_LOGI(TAG, "RST pin initialized to low");

    // Allow the ASIC reset line to settle before continuing startup.
    vTaskDelay(100 / portTICK_PERIOD_MS);
    // Init ADC
    ADC_init();

    // initialize the ESP32 NVS
    if (nvs_config_init() != ESP_OK) {
        ESP_LOGE(TAG, "Failed to init NVS");
        return;
    }

    // Check firmware version migration (resets useCustomWWW on update/downgrade)
    SYSTEM_check_firmware_migration();

    // Confirm app validity for OTA rollback
    const esp_partition_t *running = esp_ota_get_running_partition();
    esp_ota_img_states_t ota_state;
    if (esp_ota_get_state_partition(running, &ota_state) == ESP_OK) {
        if (ota_state == ESP_OTA_IMG_PENDING_VERIFY) {
            ESP_LOGI(TAG, "First boot after OTA update, confirming app validity");
            esp_ota_mark_app_valid_cancel_rollback();
        }
    }

    // Ensure SSID is initialized before any screen/self-test uses it.
    GLOBAL_STATE.SYSTEM_MODULE.ssid = nvs_config_get_string(NVS_CONFIG_WIFI_SSID);
    if (GLOBAL_STATE.SYSTEM_MODULE.ssid == NULL) {
        ESP_LOGW(TAG, "No SSID configured in NVS, using empty string");
        GLOBAL_STATE.SYSTEM_MODULE.ssid = strdup("");
        if (GLOBAL_STATE.SYSTEM_MODULE.ssid == NULL) {
            ESP_LOGE(TAG, "Failed to allocate memory for SSID");
            return;
        }
    }

    if (device_config_init(&GLOBAL_STATE) != ESP_OK) {
        ESP_LOGE(TAG, "Failed to init device config");
        return;
    }

    // Init I2C
    if (GLOBAL_STATE.DEVICE_CONFIG.pins.i2c != NULL) {
        ESP_ERROR_CHECK(i2c_bitaxe_init(GLOBAL_STATE.DEVICE_CONFIG.pins.i2c->sda, GLOBAL_STATE.DEVICE_CONFIG.pins.i2c->scl));
        ESP_LOGI(TAG, "I2C initialized successfully");
    } else {
        ESP_LOGI(TAG, "I2C pins not configured for board; skipping I2C initialization");
    }

    // wait for I2C to init
    vTaskDelay(100 / portTICK_PERIOD_MS);

    if (self_test_init(&GLOBAL_STATE) != ESP_OK) {
        ESP_LOGE(TAG, "Failed to init self test");
        return;
    }

    SYSTEM_init_system(&GLOBAL_STATE);
    if (scoreboard_init(&GLOBAL_STATE.SYSTEM_MODULE.scoreboard) != ESP_OK) {
        ESP_LOGE(TAG, "Failed to init scoreboard");
    }

    if (!GLOBAL_STATE.SELF_TEST_MODULE.is_active) {
        wifi_init(&GLOBAL_STATE);
    }

    esp_err_t system_init_ret = SYSTEM_init_peripherals(&GLOBAL_STATE);
    
    if (system_init_ret == ESP_OK) {
        if (xTaskCreate(POWER_MANAGEMENT_task, "power management", 8192, (void *) &GLOBAL_STATE, 10, NULL) != pdPASS) {
            ESP_LOGE(TAG, "Error creating power management task");
        }
        if (!GLOBAL_STATE.SELF_TEST_MODULE.is_active) {
            if (xTaskCreate(FAN_CONTROLLER_task, "fan_controller", 8192, (void *) &GLOBAL_STATE, 10, NULL) != pdPASS) {
                ESP_LOGE(TAG, "Error creating fan controller task");
            }
        }
    } else {
        ESP_LOGE(TAG, "Critical peripheral initialization failure (%s). Entering degraded mode.",
                 esp_err_to_name(system_init_ret));
    }
    
    // Read version info (from SPIFFS if custom WWW is active)
    SYSTEM_init_versions(&GLOBAL_STATE);

    if (!GLOBAL_STATE.SELF_TEST_MODULE.is_active) {
        // start the API for AxeOS
        start_rest_server(&GLOBAL_STATE);
    }

    // Pre-cache partition descriptions and space usage percentage
    SYSTEM_init_partitions(&GLOBAL_STATE);

    // Initialize BAP interface
    esp_err_t bap_ret = BAP_init(&GLOBAL_STATE);
    if (bap_ret != ESP_OK) {
        ESP_LOGE(TAG, "Failed to initialize BAP interface: %d", bap_ret);
        // Continue anyway, as BAP is not critical for core functionality
    }

    // While the device is still in setup mode (config AP up but no WiFi
    // connection), expose the BLE provisioning service so the miner can be
    // configured over Bluetooth. A short grace period avoids spinning up BLE on
    // a normal boot that connects within a few seconds. setup_ble_start() is
    // idempotent and only takes effect once the AP is actually enabled.
    int setup_ble_grace_ms = 0;
    while (!GLOBAL_STATE.SYSTEM_MODULE.is_connected) {
        if (GLOBAL_STATE.SYSTEM_MODULE.ap_enabled && setup_ble_grace_ms >= 5000) {
            setup_ble_start(&GLOBAL_STATE);
        }
        setup_ble_grace_ms += 100;
        vTaskDelay(100 / portTICK_PERIOD_MS);
    }

    // Connected to WiFi: tear down the setup BLE service to free the radio.
    setup_ble_stop();

    queue_init(&GLOBAL_STATE.stratum_queue);

    // The self-test feeds create_jobs_task a hardcoded stratum V1 mock job.
    // SYSTEM_init_system() picked the protocol from the configured pool, so pin
    // V1 here — before create_jobs_task latches it — or an SV2-configured device
    // would cast the mock mining_notify to sv2_job_t.
    if (GLOBAL_STATE.SELF_TEST_MODULE.is_active) {
        GLOBAL_STATE.stratum_protocol = STRATUM_PROTOCOL_V1;
    }

    if (system_init_ret == ESP_OK) {
        if (asic_initialize(&GLOBAL_STATE, ASIC_INIT_COLD_BOOT, 0) == 0) {
            if (!GLOBAL_STATE.SELF_TEST_MODULE.is_active) {
                return;
            }

            self_test_show_message(&GLOBAL_STATE, GLOBAL_STATE.SYSTEM_MODULE.asic_status);
            system_init_ret = ESP_FAIL;
        } else {
            if (xTaskCreate(create_jobs_task, "stratum miner", 8192, (void *) &GLOBAL_STATE, 20, NULL) != pdPASS) {
                ESP_LOGE(TAG, "Error creating stratum miner task");
            }
            if (xTaskCreate(ASIC_result_task, "asic result", 8192, (void *) &GLOBAL_STATE, 15, NULL) != pdPASS) {
                ESP_LOGE(TAG, "Error creating asic result task");
            }

            if (xTaskCreateWithCaps(hashrate_monitor_task, "hashrate monitor", 8192, (void *) &GLOBAL_STATE, 5, NULL, MALLOC_CAP_SPIRAM) != pdPASS) {
                ESP_LOGE(TAG, "Error creating hashrate monitor task");
            }
            if (xTaskCreateWithCaps(statistics_task, "statistics", 8192, (void *) &GLOBAL_STATE, 3, NULL, MALLOC_CAP_SPIRAM) != pdPASS) {
                ESP_LOGE(TAG, "Error creating statistics task");
            }
        }
    }

    if (!GLOBAL_STATE.SELF_TEST_MODULE.is_active) {
        protocol_coordinator_init(&GLOBAL_STATE);
        if (xTaskCreateWithCaps(protocol_coordinator_task, "protocol coord", 8192, (void *) &GLOBAL_STATE, 5, NULL, MALLOC_CAP_SPIRAM) != pdPASS) {
            ESP_LOGE(TAG, "Error creating protocol coordinator task");
        }
    }

    if (GLOBAL_STATE.SELF_TEST_MODULE.is_active) {
        GLOBAL_STATE.SELF_TEST_MODULE.system_init_ret = system_init_ret;
        if (xTaskCreateWithCaps(self_test_task, "self_test", 8192, (void *) &GLOBAL_STATE, 10, NULL, MALLOC_CAP_SPIRAM) != pdPASS) {
            ESP_LOGE(TAG, "Error creating self test task");
        }
    }
}

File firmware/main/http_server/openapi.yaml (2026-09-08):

openapi: 3.1.0
info:
  title: ESP-Miner API
  description: API specification for ESP-Miner HTTP server
  version: 1.0.0
  license:
    name: GNU General Public License version 3
    url: https://opensource.org/license/gpl-3-0

servers:
  - url: http://{device_ip}
    description: ESP-Miner device
    variables:
      device_ip:
        default: "192.168.1.1"
        description: IP address of the ESP-Miner device

components:
  schemas:
    GenericResponse:
      type: object
      required:
        - message
      properties:
        message:
          type: string
    UpdateSettingsResponse:
      type: object
      properties:
        status:
          type: string
          example: success
        redirect:
          type: object
          properties:
            url:
              type: string
            delay:
              type: number
            message:
              type: string
    Pool:
      type: object
      required:
        - stratumURL
        - stratumPort
        - stratumUser
      properties:
        stratumProtocol:
          type: string
          enum: [SV1, SV2]
          description: Stratum protocol
        stratumURL:
          type: string
          description: Stratum server URL
        stratumPort:
          type: integer
          description: Stratum server port
          minimum: 1
          maximum: 65535
        stratumUser:
          type: string
          description: Stratum username
        stratumPassword:
          type: string
          description: Stratum password
          writeOnly: true
        stratumSuggestedDifficulty:
          type: number
          description: Suggested difficulty
        stratumExtranonceSubscribe:
          type: boolean
          description: Enable extranonce subscribe
        stratumTLS:
          type: integer
          description: Enable stratum TLS (0=disabled, 1=enabled, 2=enabled with verification)
          minimum: 0
          maximum: 2
        stratumCert:
          type: string
          description: Stratum TLS cert
        stratumDecodeCoinbase:
          type: boolean
          description: Enable pool coinbase transaction decoding
        stratumV2ChannelType:
          type: string
          enum: [standard, extended]
          description: SV2 channel type
        stratumV2AuthorityPubkey:
          type: string
          description: SV2 authority public key for certificate verification (base58-encoded)
          pattern: "^[123456789ABCDEFGHJKLMNPQRSTUVWXYZabcdefghijkmnopqrstuvwxyz]*$"
        stratumV2RequireAuth:
          type: boolean
          description: Refuse to connect unless the SV2 server certificate is verified against the authority pubkey
        id:
          type: integer
          description: Pool NVS slot index (0 to 7)
          minimum: 0
          maximum: 7
    SharesRejectedReason:
      type: object
      required:
        - message
        - count
      properties:
        message:
          type: string
          description: Rejection reason from pool
          examples:
            - "Job not found"
        count:
          type: integer
          description: Shares rejected for this reason
    WifiNetwork:
      type: object
      required:
        - ssid
        - rssi
        - authmode
      properties:
        ssid:
          type: string
          description: Network SSID
          examples:
            - "MyWiFiNetwork"
        rssi:
          type: integer
          description: Signal strength in dBm
          examples:
            - -65
        authmode:
          type: integer
          minimum: 0
          maximum: 12
          enum:
            - 0  # WIFI_AUTH_OPEN
            - 1  # WIFI_AUTH_WEP
            - 2  # WIFI_AUTH_WPA_PSK
            - 3  # WIFI_AUTH_WPA2_PSK
            - 4  # WIFI_AUTH_WPA_WPA2_PSK
            - 5  # WIFI_AUTH_WPA2_ENTERPRISE
            - 6  # WIFI_AUTH_WPA3_PSK
            - 7  # WIFI_AUTH_WPA2_WPA3_PSK
            - 8  # WIFI_AUTH_WAPI_PSK
            - 9  # WIFI_AUTH_OWE
            - 10 # WIFI_AUTH_WPA3_ENT_192
            - 11 # WIFI_AUTH_WPA3_PSK_192 (deprecated)
            - 12 # WIFI_AUTH_WPA3_EXT_PSK (deprecated)
          description: |
            Authentication mode:
            * 0 - OPEN
            * 1 - WEP
            * 2 - WPA_PSK
            * 3 - WPA2_PSK
            * 4 - WPA_WPA2_PSK
            * 5 - WPA2_ENTERPRISE
            * 6 - WPA3_PSK
            * 7 - WPA2_WPA3_PSK
            * 8 - WAPI_PSK
            * 9 - OWE (Opportunistic Wireless Encryption)
            * 10 - WPA3_ENT_192 (Enterprise Suite-B)
            * 11 - WPA3_PSK_192 (deprecated, use WPA3_PSK)
            * 12 - WPA3_EXT_PSK (deprecated, use WPA3_PSK)
          examples:
            - 3
    HashrateMonitorAsic:
      type: object
      required:
        - total
        - domains
        - errorCount
      properties:
        total:
          type: number
          description: Hashrate
        domains:
          type: array
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

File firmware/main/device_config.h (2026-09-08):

#ifndef DEVICE_CONFIG_H_
#define DEVICE_CONFIG_H_

#include <stdint.h>
#include <stdbool.h>
#include "esp_err.h"
#include "device_pins.h"

#define THERMAL_MAX_SENSORS 2
#define NAJA_DUO_VOLTAGE_DOMAINS 2
#define GAMMA_HEX_VOLTAGE_DOMAINS 2

typedef struct GlobalState GlobalState;
typedef struct TPS546_CONFIG TPS546_CONFIG;

extern const TPS546_CONFIG TPS546_CONFIG_DEFAULT;
extern const TPS546_CONFIG TPS546_CONFIG_HEX;
extern const TPS546_CONFIG TPS546_CONFIG_GAMMA_TURBO;
extern const TPS546_CONFIG TPS546_CONFIG_NAJA_DUO;
extern const TPS546_CONFIG TPS546_CONFIG_GAMMA_HEX;

typedef enum
{
    BM1397,
    BM1366,
    BM1368,
    BM1370,
    BM1373,
} Asic;

typedef struct AsicConfig {
    Asic id;
    const char * name;
    uint16_t chip_id;
    uint16_t default_frequency_mhz;
    const uint16_t* frequency_options;
    uint16_t default_voltage_mv;
    const uint16_t* voltage_options;
    uint16_t hashrate_target;
    uint16_t difficulty;
    uint16_t core_count;
    uint16_t small_core_count;
    uint8_t hash_domains;
    uint16_t default_asic_timeout;
    uint8_t init_retry_attempts;
    float domain_hashrate_scale;
    // test values
    float hashrate_test_percentage_target;
} AsicConfig;

typedef enum
{
    MAX,
    ULTRA,
    HEX,
    SUPRA,
    GAMMA,
    GAMMA_DUO,
    SUPRA_HEX,
    GAMMA_HEX,
    GAMMA_TURBO,
    NAJA_DUO,
    BITCOINMINER,
} Family;

typedef struct FamilyConfig {
    Family id;
    const char * name;
    AsicConfig asic;
    uint8_t asic_count;
    uint16_t max_power;
    uint16_t power_offset;
    uint16_t nominal_voltage;
    uint16_t voltage_domains;
    const char * swarm_color;
    const TPS546_CONFIG * tps546_config;
} FamilyConfig;

typedef struct DeviceConfig {
    const char * board_version;
    FamilyConfig family;
    DevicePins pins;
    bool plug_sense;
    bool asic_enable;
    bool asic_enable_active_high;
    bool EMC2101 : 1;
    bool EMC2103 : 1;
    bool EMC2302 : 1;
    bool emc_direct_pwm : 1;
    bool emc_internal_temp : 1;
    bool TMP1075 : 1;
    uint8_t emc_ideality_factor;
    uint8_t emc_beta_compensation;
    bool temp_flip;
    bool display_flip : 1;
    int8_t temp_offset;
    bool DS4432U : 1;
    bool INA260  : 1;
    bool TPS546  : 1;
    // test values
    uint16_t power_consumption_target;
    uint16_t power_consumption_margin;
    uint16_t self_test_fan_target_rpm;
} DeviceConfig;

static const uint16_t BM1397_FREQUENCY_OPTIONS[]   = {400, 425, 450, 475, 485, 500, 525, 550, 575, 600, 0};
static const uint16_t BM1366_FREQUENCY_OPTIONS[]   = {400, 425, 450, 475, 485, 500, 525, 550, 575,      0};
static const uint16_t BM1368_FREQUENCY_OPTIONS[]   = {400, 425, 450, 475, 485, 490, 500, 525, 550, 575, 0};
static const uint16_t BM1370_FREQUENCY_OPTIONS[]   = {400, 490, 525, 550, 600, 625, 690,                0};
static const uint16_t BM1373_FREQUENCY_OPTIONS[]   = {327, 350, 375, 380, 400, 410,                     0};
static const uint16_t BM1370_FRQUENCY_XP_OPTIONS[] = {350, 375, 380, 400, 410,                        0};

static const uint16_t BM1397_VOLTAGE_OPTIONS[] = {1100, 1150, 1200, 1250, 1300, 1350, 1400, 1450, 1500, 0};
static const uint16_t BM1366_VOLTAGE_OPTIONS[] = {1100, 1150, 1200, 1250, 1300,                         0};
static const uint16_t BM1368_VOLTAGE_OPTIONS[] = {1100, 1150, 1166, 1200, 1250, 1300,                   0};
static const uint16_t BM1370_VOLTAGE_OPTIONS[] = {1000, 1060, 1100, 1150, 1200, 1250,                   0};
static const uint16_t BM1373_VOLTAGE_OPTIONS[] = {1000, 1060, 1100, 1150, 1200, 1250,                   0};
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

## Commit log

2026-02-14 finish copying schematic from bitaxe
    [bitcoinMiner.kicad_sch, bm1370.kicad_sch, esp32.kicad_sch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]
2026-02-16 add ethernet sheet
    [ethernet.kicad_sch]
2026-02-16 update other sheets
    [bm1370.kicad_sch, esp32.kicad_sch, fan.kicad_sch]
2026-02-16 update power sheet
    [power.kicad_sch]
2026-02-16 random updates
    [bitcoinMiner.kicad_pcb]
2026-03-09 update pcb
    [bitcoinMiner.kicad_pcb, bm1370.kicad_sch]
2026-03-10 clean files
    [21-0164B_L622-1_MXM.step, 2R5TPE220MAFB.step, 470531000.stp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]
2026-08-13 finish schematic
    [bitcoinMiner.kicad_pcb, bitcoinMiner.kicad_sch, bm1370.kicad_sch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]
2026-08-13 add neopoixels and spinrender
    [.bitcoinMiner.spinrender-src.kicad_pcb, .bitcoinMiner.spinrender-tmp.kicad_pcb, bitcoinMiner.kicad_pcb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]
2026-08-16 pcb updates and remove ethernet
    [bitcoinMiner.kicad_pcb, ethernet.kicad_sch]
2026-08-20 add images and journal
    [.bitcoinMiner.spinrender-src.kicad_pcb, .bitcoinMiner.spinrender-tmp.kicad_pcb, bitcoinMiner.kicad_pcb]
2026-09-08 firmware und bom
    [BOM.csv, bom.csv, config-102.csv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]
